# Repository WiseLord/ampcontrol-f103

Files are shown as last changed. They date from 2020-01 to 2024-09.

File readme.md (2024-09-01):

# Ampcontrol (STM32F103 / F303 version)

Ampcontrol is an control module for your DIY audio amplifier.
It supports various I²C-controlled audioprocessors and FM tuners.
Also, some other third-party devices are supported.

Some videos related to the device can be found at
[Youtube](https://www.youtube.com/playlist?list=PLfv57leyFFd1C61HgnKE3e_OFIXMBtf-D)

## Hardware support

- Graphic color TFT displays based on various controllers:
  - 160x128: ILI9163, S6D0144, ST7735;
  - 176x132: L2F50126, LPH9157, LS020, SSD1286A;
  - 220x176: HX8340, ILI9225, LGDP4524, S6D0164;
  - 320x240: HX8347A, HX8347D, ILI9320, ILI9341, MC2PA8201, S6D0129, S6D0139, SPFD5408, SSD1289, SSD2119;
  - 400x240: ILI9327, S6D04D1, ST7793;
  - 480x320: HX8357C, ILI9481, ILI9486, R61581, RM68140, ST7796S.

- Audio processors with I²C bus:
  - TDA7439, TDA731X, PT232X, TDA7418, TDA7719.

- FM tuners with I²C bus:
  - RDA580X, SI470X, TEA5767.

- Bluetooth modules
  - CSR8645, BK8000L (GPIO-based control via PCF8574x I²C expander);
  - BT201 (USART-based control).

- USB HID
  - Meida player on the PC can be controlled (Play/Pause and so on) by the device.

- KaRadio and MPD support
  - The device can act as "KaRadio plugin" via USART2 to add web radio support via ESP32. Alternatively, 
it can control MPD server running on Linux (for example, Raspberry PI).

More specific info can be found in [documentation](doc) pages.

## Building the code

[GNU Arm Embedded Toolchain](https://developer.arm.com/tools-and-software/open-source-software/developer-tools/gnu-toolchain/gnu-rm/downloads)
is required to build the project.

The project build system is based on [GNU Make](https://www.gnu.org/software/make/).
Linux users must have it already installed or they can easily do it.
For Windows users there is a port exists.
In both cases, both toolchain and make binaries should be added to the system PATH.

The process of building is very simple and doesn't depend on any other software installed.

### Default build (ILI9341 display with SPI wiring):

`make`

### Build for the specific STM32 MCUs, display and wiring:

`make STM32_MCU=F303CB DISPLAY=R61581 DISPVAR=8BIT`

The list of supported display controllers and MCUs can be found in Makefile or build_all.sh script.

## Schematics and wiring

The schematic and PCB files for the device itself in KiCad format can be found 
in [kicad/ampcontrol-f103](kicad/ampcontrol-f103) directory.

## Useful links

* [Firmware releases](https://github.com/WiseLord/ampcontrol-f103/releases)

* [The article (in Russian)](https://radiokot.ru/artfiles/6484/)

* [Forum thread (in Russian)](https://radiokot.ru/forum/viewtopic.php?f=2&t=158605)

* [Youtube playlist](https://www.youtube.com/playlist?list=PLfv57leyFFd1C61HgnKE3e_OFIXMBtf-D)

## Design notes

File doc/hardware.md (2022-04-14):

# TFT display

The project supports Graphic color TFT displays based on various controllers:

- 160x128: ILI9163, S6D0144, ST7735
- 176x132: L2F50126, LPH9157, LS020, SSD1286A
- 220x176: HX8340, ILI9225, LGDP4524, S6D0164
- 320x240: HX8347A, HX8347D, ILI9320, ILI9341, MC2PA8201, S6D0129, S6D0139, SPFD5408, SSD1289, SSD2119
- 400x240: ILI9327, S6D04D1, ST7793
- 480x320: HX8357C, ILI9481, ILI9486, R61581, RM68140, ST7796S

## 8-bit display connection:

D0-D7 (data bus): PB0-PB7
RD (read pin): pull to 3.3V
WR: (write pin): PB15
RS: (register select): PB14
CS: (chip select): PB12
RST: (reset): pull to 3.3V
BCKL: (backlight): PC13

## SPI display connection
CS: (chip select): PB12
RST: (reset): pull to 3.3V
DC: (data/command): PB14
SDI: (slave data input): PB15 (hardware SPI2 MOSI)
SCK: (slave clock): PB13 (hardware SPI2 SCK)
LED: (backlight): PC13
SDO: (slave data ooutput): pull to 3.3V

## Audiocontrollers and FM tuners

Most of the external chips are connected via I²C bus (hardware SPI1)

SDA: PB9
SCL: PB8

Si4703 tuner with 32768kHz quartz also needs reset pin connection:

RST: PA15

## MUTE and STBY control

When entering standby mode, it's useful to disable powering some parts of the whole projects
(like audio amplifier, audioprocessor, etc). So, only ampcontrol control module itself can
be left powered with lower display brighness. STBY pin can be used to control a relay or
another swtitch doing this.

Also, switching between inputs, powering on/off can produce audible clicks in acoustic system.
MUTE pin can be used to mute an amplifier at these moments.

STBY: PB10
MUTE: PB11

## Remote control

Standard TSOP IR receiver is used to get control commands from IR remote.

IR: PA8

## BT201 bluetooth module

USART1 used for communications with the module. So, playback is fully controlled as well as
an information about current song from USB or SDCARD is retreived

TX: PA9
RX: PA10

## Bluetooth modules like BK8000L or CSR8645

These modules don't have known interface to communicate with MCUs. But they have
GPIOs to connect buttons for such functions as PLAY/PAUSE and so on.

To control such kind of bluetooth modules, it's possible to use PCF8574 I²C bus expander
to emulate buttons presses to execute corresponding functions. It's connected to the project
via I²C line:

SDA: PB9
SCL: PB8

Then, the correct I²C address (depends on PCF8574 address input pins conditions)
should be selected in ampcontrol settings.

PCF5874 is connected to the BT module in this way (see i2cexp.h):

NEXT_TRACK: P5
PREV_TRACK: P4
NEXT_INPUT: P3
PLAY_PAUSE: P2

To emulate button press, PCF8574 sends short (200ms) positive impulse on the pin.

## KaRadio or MPD

The device can act as a "plugin" for KaRadio/KaRadio32 projects. The control and all
communications are done via USART2 connection

TX: PA2
RX: PA3

Also, instead of KaRadio it's possible to control MPD (Music Player Daemon). The board with
MPD (e.g. Raspberry Pi or alternative) need to be prepared and it should include mpd-uart.py 
script running. This script makes implements a communication between Ampcontrol's USART2 and
the board's MPD daemon. Python3 packages pyserial and python-mpd2 need to be installed.

## USB

When connectetd to the PC via hardware USB, the project acts as "USB keyboard" and sends
multimedia keys to the PC when a button on front panel or remote control is pressed. Thus,
playback in active multimedia player on PC supporting media keys can be controlled.

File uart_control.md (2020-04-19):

# UART control description

Commands to control the device via uart are shown below.

Lines starting with '##' are the output from the device,
an answer on user actions or control commands.

The commands set is under development and will be extended
in the future.

## 1. Power control

**amp.on**                      - Power on  
  ##AMP.STATUS#: ACTIVE  
  ##AMP.AUDIO.IC#: TDA7439  
  ##AMP.AUDIO.INPUT#: 0  
  ##AMP.AUDIO.VOLUME#: -50  
  ##AMP.AUDIO.BASS#: 3  
  ##AMP.AUDIO.MIDDLE#: 1  
  ##AMP.AUDIO.TREBLE#: 2  
  ##AMP.AUDIO.FRONTREAR#: 0  
  ##AMP.AUDIO.BALANCE#: 0  
  ##AMP.AUDIO.CENTER#: 0  
  ##AMP.AUDIO.SUBWOOFER#: 0  
  ##AMP.AUDIO.PREAMP#: 0  

**amp.off**                     - Power off  
  ##AMP.STATUS#: STANDBY  

**amp.switch**                  - Toggle the power  
  ##AMP.STATUS#: STANDBY  

**amp.status**                  - Show current power status  
  ##AMP.STATUS#: ACTIVE  

Commands above work always. Commands below work only in ACTIVE status

## 2. Audio control

**amp.audio**                   - Show selected audioproc name  
  ##AMP.AUDIO.IC#: TDA7439  

### Inputs

**amp.input**                   - Show current input  
 ##AMP.AUDIO.INPUT#: 2  

**amp.input 1**                 - Select input (starting from 0)  
  ##AMP.AUDIO.INPUT#: 1  
  ##AMP.AUDIO.GAIN#: 0  

**amp.input.next**              - Switch to next input  
  ##AMP.AUDIO.INPUT#: 3  
  ##AMP.AUDIO.GAIN#: 0  

**amp.input.prev**              - Switch to previous input  
  ##AMP.AUDIO.INPUT#: 2  
  ##AMP.AUDIO.GAIN#: 0  

### Volume, bass, middle. treble:

**amp.volume**                  - Show volume level  
  ##AMP.AUDIO.VOLUME#: -53  

**amp.bass.inc**                - Increase bass level  
  ##AMP.AUDIO.BASS#: 4  

**amp.middle.dec**              - Decrease middle level  
  ##AMP.AUDIO.MIDDLE#: 0  

**amp.treble 3**                - Decrease treble level  
  ##AMP.AUDIO.TREBLE#: 3  

## 3. Tuner control

**amp.tuner**                   - Show selected tuner name  
  ##AMP.TUNER.IC#: RDA5807  

**amp.tuner.freq**              - Show tuned frequency  
  ##AMP.TUNER.FREQ#: 9950  

**amp.tuner.freq 9980**         - Tune frequency  
  ##AMP.TUNER.FREQ#: 9980

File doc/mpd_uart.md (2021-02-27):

# MPD UART setup

Music Player Daemon is an application for playing music. It can be installed in any Linux, e.g:

`sudo apt install mpd`

MPD itself is a server part that only plays music. To control it, another application (client)
should be used.

Script mpd-uart.py acts like a client for MPD and is responsible for communications between
MPD daemon and Ampcontrol. It needs some python packages installed:

`sudo apt install pyserial`
`sudo apt install python-mpd2`

## Running on Linux PC

The easiest way is using USB-UART dongle. In Linux it is usually visible in system as /dev/ttyUSB0.
So, to run mpd-uart the following command should be executed:

`python3 /path/to/mpd-uart.py -p /dev/ttyUSB0`

Now, when USB-UART is connected to Ampcontrol's USART2, it's possible to control MPD instance on PC.
It works until the script is running.

## Running on Raspberry PI

Raspberry PI have GPIO header than includes UART pins. Firstly, it should be enabled on the board.
For example, in Raspi OS it can be done via "raspi-config" utility. Alternatively, it can be done
manually, by adding "enable_uart=1" parameter to /boot/config.txt file and removing any 'console=XXX`
parameters from /boot/cmdline.txt, except XXX=tty1.

After reboot the header UART (pins 8 and 10) are accessable, and mpd-uart (for instance, placed in
/home/pi/ folder) can be run as:

`python3 /home/pi/mpd-uart.py -p /dev/ttyS0`

Alternatively, the port can be specified in the script mpd-uart.py itself.

Probably, '/dev/serial0' should be used depending on RPi version.

## Daemon mode for mpd-uart.py

It's not convenient to run mpd-uart.py manually. So, it's good idea to run it as a system service.
For Raspi OS, that uses systemd, mpd-uart.service config was written.

To make it work, "mpd-uart.service" file should be placed to /etc/systemd/system/. After the new
service can be enabled for autoboot via the following command:

`sudo systemctl enable mpd-uart.service`

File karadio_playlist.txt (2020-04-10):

{"Name":"","URL":"","File":"","Port":"0","ovol":"0"}
{"Name":"Euroradio FM - SoftRock","URL":"stream1.euroradio.fm","File":"/euroradio3","Port":"8000","ovol":"0"}
{"Name":"Euroradio FM - Толькі BY","URL":"stream1.euroradio.fm","File":"/euroradio4","Port":"8000","ovol":"0"}
{"Name":"Euroradio FM - Alternative","URL":"stream1.euroradio.fm","File":"/euroradio1","Port":"8000","ovol":"0"}
{"Name":"Альфа Радио 107.9","URL":"listen.alpha.by","File":"/","Port":"8009","ovol":"0"}
{"Name":"Мелодии века 96.2","URL":"93.84.112.253","File":"/MV128","Port":"8010","ovol":"0"}
{"Name":"Радио UNISTAR 99.5 (Hot AC)","URL":"stream.hoster.by","File":"/unistar/unistar-256/icecast.audio","Port":"80","ovol":"0"}
{"Name":"Беларусь 102.0","URL":"video.tvr.by","File":"/belfm","Port":"8000","ovol":"0"}
{"Name":"Канал Культура 1125","URL":"video.tvr.by","File":"/culture","Port":"8000","ovol":"0"}
{"Name":"Радио Мир 107.1","URL":"217.23.126.106","File":"/radio2.mir","Port":"8002","ovol":"0"}
{"Name":"Радыё Рацыя 99.2","URL":"air.racyja.com","File":"/racja256","Port":"8000","ovol":"0"}
{"Name":"Юмор FM 93.7","URL":"live.humorfm.by","File":"/veseloe","Port":"8000","ovol":"0"}
{"Name":"Радыё Сталіца 105.1","URL":"video.tvr.by","File":"/stolica","Port":"8000","ovol":"0"}
{"Name":"","URL":"","File":"","Port":"0","ovol":"0"}
{"Name":"","URL":"","File":"","Port":"0","ovol":"0"}
{"Name":"","URL":"","File":"","Port":"0","ovol":"0"}
{"Name":"","URL":"","File":"","Port":"0","ovol":"0"}
{"Name":"","URL":"","File":"","Port":"0","ovol":"0"}
{"Name":"","URL":"","File":"","Port":"0","ovol":"0"}
{"Name":"","URL":"","File":"","Port":"0","ovol":"0"}
{"Name":"","URL":"","File":"","Port":"0","ovol":"0"}
{"Name":"","URL":"","File":"","Port":"0","ovol":"0"}
{"Name":"","URL":"","File":"","Port":"0","ovol":"0"}
{"Name":"","URL":"","File":"","Port":"0","ovol":"0"}
{"Name":"","URL":"","File":"","Port":"0","ovol":"0"}
{"Name":"","URL":"","File":"","Port":"0","ovol":"0"}
{"Name":"","URL":"","File":"","Port":"0","ovol":"0"}
{"Name":"","URL":"","File":"","Port":"0","ovol":"0"}
{"Name":"","URL":"","File":"","Port":"0","ovol":"0"}
{"Name":"","URL":"","File":"","Port":"0","ovol":"0"}
{"Name":"","URL":"","File":"","Port":"0","ovol":"0"}
{"Name":"","URL":"","File":"","Port":"0","ovol":"0"}
{"Name":"","URL":"","File":"","Port":"0","ovol":"0"}
{"Name":"","URL":"","File":"","Port":"0","ovol":"0"}
{"Name":"","URL":"","File":"","Port":"0","ovol":"0"}
{"Name":"","URL":"","File":"","Port":"0","ovol":"0"}
{"Name":"","URL":"","File":"","Port":"0","ovol":"0"}
{"Name":"","URL":"","File":"","Port":"0","ovol":"0"}
{"Name":"","URL":"","File":"","Port":"0","ovol":"0"}
{"Name":"","URL":"","File":"","Port":"0","ovol":"0"}
{"Name":"","URL":"","File":"","Port":"0","ovol":"0"}
{"Name":"","URL":"","File":"","Port":"0","ovol":"0"}
{"Name":"","URL":"","File":"","Port":"0","ovol":"0"}
{"Name":"","URL":"","File":"","Port":"0","ovol":"0"}
{"Name":"","URL":"","File":"","Port":"0","ovol":"0"}
{"Name":"","URL":"","File":"","Port":"0","ovol":"0"}
{"Name":"","URL":"","File":"","Port":"0","ovol":"0"}
{"Name":"","URL":"","File":"","Port":"0","ovol":"0"}
{"Name":"","URL":"","File":"","Port":"0","ovol":"0"}
{"Name":"","URL":"","File":"","Port":"0","ovol":"0"}
{"Name":"VOA Learning English (США)","URL":"voa-91.akacast.akamaistream.net","File":"/7/913/314276/v1/ibb.akacast.akamaistream.net/voa-91.m3u","Port":"80","ovol":"0"}
{"Name":"BBC World Service UK","URL":"bbcmedia.ic.llnwd.net","File":"/stream/bbcwssc_mp1_ws-eieuk","Port":"80","ovol":"0"}
{"Name":"BBC Radio 4 Extra (Юмор)","URL":"bbcmedia.ic.llnwd.net","File":"/stream/bbcmedia_radio4extra_mf_p","Port":"80","ovol":"0"}
{"Name":"","URL":"","File":"","Port":"0","ovol":"0"}
{"Name":"","URL":"","File":"","Port":"0","ovol":"0"}
{"Name":"","URL":"","File":"","Port":"0","ovol":"0"}
{"Name":"","URL":"","File":"","Port":"0","ovol":"0"}
{"Name":"","URL":"","File":"","Port":"0","ovol":"0"}
{"Name":"","URL":"","File":"","Port":"0","ovol":"0"}
{"Name":"","URL":"","File":"","Port":"0","ovol":"0"}
{"Name":"","URL":"","File":"","Port":"0","ovol":"0"}
{"Name":"","URL":"","File":"","Port":"0","ovol":"0"}
{"Name":"","URL":"","File":"","Port":"0","ovol":"0"}
{"Name":"","URL":"","File":"","Port":"0","ovol":"0"}
{"Name":"","URL":"","File":"","Port":"0","ovol":"0"}
{"Name":"","URL":"","File":"","Port":"0","ovol":"0"}
{"Name":"","URL":"","File":"","Port":"0","ovol":"0"}
{"Name":"","URL":"","File":"","Port":"0","ovol":"0"}
{"Name":"","URL":"","File":"","Port":"0","ovol":"0"}
{"Name":"","URL":"","File":"","Port":"0","ovol":"0"}
{"Name":"","URL":"","File":"","Port":"0","ovol":"0"}
{"Name":"","URL":"","File":"","Port":"0","ovol":"0"}
{"Name":"","URL":"","File":"","Port":"0","ovol":"0"}
{"Name":"","URL":"","File":"","Port":"0","ovol":"0"}
{"Name":"","URL":"","File":"","Port":"0","ovol":"0"}
{"Name":"","URL":"","File":"","Port":"0","ovol":"0"}
{"Name":"","URL":"","File":"","Port":"0","ovol":"0"}
{"Name":"","URL":"","File":"","Port":"0","ovol":"0"}
{"Name":"","URL":"","File":"","Port":"0","ovol":"0"}
{"Name":"","URL":"","File":"","Port":"0","ovol":"0"}
{"Name":"","URL":"","File":"","Port":"0","ovol":"0"}
{"Name":"","URL":"","File":"","Port":"0","ovol":"0"}
{"Name":"","URL":"","File":"","Port":"0","ovol":"0"}
{"Name":"","URL":"","File":"","Port":"0","ovol":"0"}
{"Name":"","URL":"","File":"","Port":"0","ovol":"0"}
{"Name":"","URL":"","File":"","Port":"0","ovol":"0"}
{"Name":"","URL":"","File":"","Port":"0","ovol":"0"}
{"Name":"","URL":"","File":"","Port":"0","ovol":"0"}
{"Name":"","URL":"","File":"","Port":"0","ovol":"0"}
{"Name":"","URL":"","File":"","Port":"0","ovol":"0"}
{"Name":"","URL":"","File":"","Port":"0","ovol":"0"}
{"Name":"","URL":"","File":"","Port":"0","ovol":"0"}
{"Name":"","URL":"","File":"","Port":"0","ovol":"0"}
{"Name":"","URL":"","File":"","Port":"0","ovol":"0"}
{"Name":"","URL":"","File":"","Port":"0","ovol":"0"}
{"Name":"","URL":"","File":"","Port":"0","ovol":"0"}
{"Name":"","URL":"","File":"","Port":"0","ovol":"0"}
{"Name":"","URL":"","File":"","Port":"0","ovol":"0"}
{"Name":"","URL":"","File":"","Port":"0","ovol":"0"}
{"Name":"","URL":"","File":"","Port":"0","ovol":"0"}
{"Name":"RTL","URL":"streaming.radio.rtl.fr","File":"/rtl-1-48-192","Port":"80","ovol":"-4"}
{"Name":"RJM French","URL":"listen.radionomy.com","File":"/rjm-french.m3u","Port":"80","ovol":"0"}
{"Name":"France1Max","URL":"listen.radionomy.com","File":"/france1max.m3u","Port":"80","ovol":"0"}
{"Name":"Golden50/70sHits","URL":"listen.radionomy.com","File":"/golden-50-70s-hits","Port":"80","ovol":"0"}
{"Name":"Nostalgie Chansons Francaises","URL":"cdn.nrjaudio.fm","File":"/adwz1/fr/30611/aac_64.mp3","Port":"80","ovol":"0"}
{"Name":"Romantic Dreams","URL":"listen.radionomy.com","File":"/romanticdreams","Port":"80","ovol":"0"}
{"Name":"MusicOnly FM","URL":"listen.radionomy.com","File":"/musiconly-fm","Port":"80","ovol":"0"}
{"Name":"Nice oldies","URL":"listen.radionomy.com","File":"/niceoldies","Port":"80","ovol":"0"}
{"Name":"Radio 45 tours","URL":"listen.radionomy.com","File":"/45tours","Port":"80","ovol":"0"}
{"Name":"RFI Monde","URL":"live02.rfi.fr","File":"/rfimonde-64.mp3","Port":"80","ovol":"0"}
{"Name":"Alpes 1 Gap","URL":"alpes1gap.ice.infomaniak.ch","File":"/alpes1gap-high.mp3","Port":"80","ovol":"0"}
{"Name":"Alpes 1 Années 80","URL":"allzic08.ice.infomaniak.ch","File":"/allzic08.mp3","Port":"80","ovol":"0"}
{"Name":"Alpes 1 Années 90","URL":"allzic24.ice.infomaniak.ch","File":"/allzic24.mp3","Port":"80","ovol":"0"}
{"Name":"Autoroute info sud","URL":"media.autorouteinfo.fr","File":"/direct_sud.mp3.m3u","Port":"8000","ovol":"0"}
{"Name":"Autoroute Info Nord","URL":"media.autorouteinfo.fr","File":"/direct_nord.mp3.m3u","Port":"8000","ovol":"0"}
{"Name":"California 101","URL":"www.california101radio.com","File":"/california101.pls","Port":"80","ovol":"0"}
{"Name":"Chante France","URL":"stream1.chantefrance.com","File":"/Chante_France.m3u","Port":"80","ovol":"0"}
{"Name":"Radio Grenouille","URL":"live.radiogrenouille.com","File":"/live.m3u","Port":"80","ovol":"0"}
{"Name":"Alter Nantes","URL":"diffusion.lafrap.fr","File":"/alternantes.mp3.m3u","Port":"80","ovol":"0"}
{"Name":"Impact FM","URL":"broadcast.infomaniak.ch","File":"/impactfm-128.mp3.m3u","Port":"80","ovol":"0"}
{"Name":"MFM","URL":"mfm.ice.infomaniak.ch","File":"/mfm-128.mp3","Port":"80","ovol":"0"}
{"Name":"OUI FM","URL":"broadcast.infomaniak.ch","File":"/ouifm-high.mp3.m3u","Port":"80","ovol":"0"}
{"Name":"OUI FM Alternatif","URL":"broadcast.infomaniak.net","File":"/ouifm2.mp3.m3u","Port":"80","ovol":"0"}
{"Name":"OUI FM Collector","URL":"ouifm3.ice.infomaniak.ch","File":"/ouifm3.mp3.m3u","Port":"80","ovol":"0"}
{"Name":"Hot Mix","URL":"www.hotmixradio.fr","File":"/hotmixhit.m3u","Port":"80","ovol":"0"}
{"Name":"Classical WETA 90.9 FM - Washington D.C.","URL":"38.100.128.106","File":"/listen.pls?sid=1","Port":"8000","ovol":"0"}
{"Name":"Radio Bloodstream","URL":"uk1.internet-radio.com","File":"/live.m3u","Port":"8294","ovol":"0"}
{"Name":"Classic Rock Florida","URL":"us2.internet-radio.com","File":"/listen.pls","Port":"8046","ovol":"0"}
{"Name":"Lala Radio","URL":"broadcast.infomaniak.ch","File":"/lalaradio-high.mp3.m3u","Port":"80","ovol":"0"}
{"Name":"SUN - LE SON UNIQUE A NANTES ","URL":"80.82.229.202","File":"/sunhd.mp3","Port":"8000","ovol":"0"}
{"Name":"Los 40 Principales","URL":"provisioning.streamtheworld.com","File":"/pls/LOS40.pls","Port":"80","ovol":"0"}
{"Name":"Earth Uk","URL":"media-ice.musicradio.com","File":"/HeartLondonMP3.m3u","Port":"80","ovol":"0"}
{"Name":"Public Domain Classical - Swiss Internet Radio","URL":"www.swissradio.ch","File":"/streams/6034.asx","Port":"80","ovol":"0"}
{"Name":"Minster Radio Uk","URL":"str1.sad.ukrd.com","File":"/minster.m3u","Port":"80","ovol":"0"}
{"Name":"Zenith Classic Rock Dublin","URL":"148.163.81.10","File":"/listen.pls?sid=1","Port":"8006","ovol":"0"}
{"Name":"Vibration FM Suise","URL":"vibration.stream2net.eu","File":"/listen.pls","Port":"8130","ovol":"0"}
{"Name":"Vibration PopRock Suisse","URL":"vibrationpoprock.stream2net.eu","File":"/listen.pls","Port":"8260","ovol":"0"}
{"Name":"Vibration Latina Suisse","URL":"vibracionlatina.stream2net.eu","File":"/listen.pls","Port":"8410","ovol":"0"}
{"Name":"Vibration classic hit Suisse","URL":"vibrationclassic80.stream2net.eu","File":"/listen.pls","Port":"8060","ovol":"0"}
{"Name":"Traxx Suisse","URL":"traxx001.ice.infomaniak.ch","File":"/traxx009-low.mp3.m3u","Port":"80","ovol":"0"}
{"Name":"Rhone FM","URL":"broadcast.infomaniak.ch","File":"/rhonefm-high.mp3.m3u","Port":"80","ovol":"0"}
{"Name":"Motown Magic Oldies","URL":"airspectrum.cdnstream1.com","File":"/1302_192.m3u","Port":"8024","ovol":"0"}
{"Name":"California-101 The Westcoast Radio","URL":"www.california101radio.com","File":"/california101.pls","Port":"80","ovol":"0"}
{"Name":"All Request Show","URL":"www.streamvortex.com","File":"/listen.pls?sid=1","Port":"10230","ovol":"0"}
{"Name":"SALSA BRAVA RADIO","URL":"206.190.130.180","File":"/","Port":"8053","ovol":"0"}
{"Name":"1.FM - ABSOLUTE TOP 40 RADIO","URL":"69.46.90.245","File":"/","Port":"8078","ovol":"0"}
{"Name":"Magic Oldies Florida","URL":"listen.shoutcast.com","File":"/MagicOldiesFlorida","Port":"80","ovol":"0"}
{"Name":"Coast FM TENERIFE","URL":"uk1.internet-radio.com","File":"/","Port":"15614","ovol":"0"}
{"Name":"French Radio London","URL":"radio.canstream.co.uk","File":"/live.mp3.m3u","Port":"8100","ovol":"0"}
{"Name":"VOXINOX la webradio des Jeunes Seniors","URL":"94.23.41.123","File":"/","Port":"8010","ovol":"0"}
{"Name":"Voxinox 2","URL":"94.23.41.123","File":"/;?.mp3","Port":"8020","ovol":"0"}
{"Name":"Sud Radio","URL":"start-sud.ice.infomaniak.ch","File":"/start-sud-high.mp3","Port":"80","ovol":"0"}
{"Name":"100% Hit","URL":"100radio-hit.ice.infomaniak.ch","File":"/100radio-hit-128.mp3","Port":"80","ovol":"0"}
{"Name":"100% 80","URL":"100radio-80.ice.infomaniak.ch","File":"/100radio-80-128.mp3","Port":"80","ovol":"0"}
{"Name":"100% 90","URL":"100radio-90.ice.infomaniak.ch","File":"/100radio-90-64.aac","Port":"80","ovol":"0"}
{"Name":"100% Carcassonne","URL":"100radio-carcassonne.ice.infomaniak.ch","File":"/100radio-carcassonne-128.mp3","Port":"80","ovol":"0"}
{"Name":"Ringfm","URL":"shout.babahh.com","File":"/ringfm","Port":"80","ovol":"0"}
{"Name":"Europa FM Spain","URL":"212.129.60.86","File":"/listen.pls","Port":"9968","ovol":"0"}
{"Name":"Cadena Spain","URL":"provisioning.streamtheworld.com","File":"/pls/CADENADIAL.pls","Port":"80","ovol":"0"}
{"Name":"Europa FM Spain","URL":"212.129.60.86","File":"/listen.pls","Port":"9968","ovol":"0"}
{"Name":"Classic Hits 4FM Ireland","URL":"sirius.shoutca.st","File":"/listen.pls?sid=1","Port":"8166","ovol":"0"}
{"Name":"Sunshine Ireland","URL":"sirius.shoutca.st","File":"/listen.pls?sid=1","Port":"8291","ovol":"0"}
{"Name":"Antenna 1 Italy","URL":"s3.mediastreaming.it","File":"/listen.pls","Port":"7568","ovol":"0"}
{"Name":"Antenna 2 Italy","URL":"wma03.fluidstream.net","File":"/listen.pls","Port":"9070","ovol":"0"}
{"Name":"FM Italia Italy","URL":"onair7.xdevel.com","File":"/listen.pls","Port":"8700","ovol":"0"}
{"Name":"Onda Libera Italy","URL":"s6.mediastreaming.it","File":"/listen.pls","Port":"9064","ovol":"0"}
{"Name":"Hi On Line Pop netherland","URL":"mediaserv30.live-streams.nl","File":"/","Port":"8086","ovol":"0"}
{"Name":"Hi On Line World","URL":"mediaserv38.live-streams.nl","File":"/","Port":"8027","ovol":"0"}
{"Name":"Hi On Line Latin","URL":"mediaserv33.live-streams.nl","File":"/","Port":"8034","ovol":"0"}
{"Name":"Hi On Line Gold","URL":"mediaserv30.live-streams.nl","File":"/","Port":"8000","ovol":"0"}
{"Name":"trancebase","URL":"listen.trancebase.fm","File":"/tunein-aacplus-pls?sid=1","Port":"80","ovol":"0"}
{"Name":"PARTY VIBE RADIO ","URL":"www.partyviberadio.com","File":"/listen.pls?sid=1","Port":"8000","ovol":"0"}
{"Name":"Party Vibe Top 40","URL":"www.partyviberadio.com","File":"/listen.pls?sid=1","Port":"8024","ovol":"0"}
{"Name":"The Cardigans","URL":"stream.pcradio.biz","File":"/The_Cardigans-hi","Port":"8000","ovol":"0"}
{"Name":"The Beach Boys","URL":"stream.pcradio.biz","File":"/The_Beach_Boys-hi","Port":"8000","ovol":"0"}
{"Name":"Top 200","URL":"stream.pcradio.biz","File":"/Top_200-hi","Port":"8000","ovol":"0"}
{"Name":"The Corrs","URL":"stream.pcradio.biz","File":"/The_Corrs-hi","Port":"8000","ovol":"0"}
{"Name":"Pink Floyd","URL":"stream.pcradio.biz","File":"/Pink_Floyd-hi","Port":"8000","ovol":"0"}
{"Name":"BoneyM","URL":"stream.pcradio.biz","File":"/BoneyM-hi","Port":"8000","ovol":"0"}
{"Name":"Nirvana","URL":"stream.pcradio.biz","File":"/Nirvana-hi","Port":"8000","ovol":"0"}
{"Name":"The Prodigy","URL":"stream.pcradio.biz","File":"/The_Prodigy-hi","Port":"8000","ovol":"0"}
{"Name":"Radio Ici et Maintenant","URL":"radio.rim952.fr","File":"/stream.ogg.m3u","Port":"8001","ovol":"0"}
{"Name":"Radio libertaire","URL":"ecoutez.radio-libertaire.org","File":"/radiolib.m3u","Port":"8080","ovol":"0"}
{"Name":"Russe","URL":"stream.pcradio.biz","File":"/Ruki_Vverh-hi","Port":"8000","ovol":"0"}
{"Name":"Radio 101 Zagreb","URL":"live.radio101.hr","File":"/listen.pls","Port":"7066","ovol":"0"}
{"Name":"DI Radio Digital impulse","URL":"5.39.71.159","File":"/listen.pls?sid=1","Port":"8110","ovol":"0"}
{"Name":"test2","URL":"provisioning.streamtheworld.com","File":"/pls/program1aac.pls","Port":"80","ovol":"0"}
{"Name":"deltaradio_indie","URL":"stream.pcradio.biz","File":"/deltaradio_indie-low","Port":"8000","ovol":"0"}
{"Name":"Top club radionomy","URL":"listen.radionomy.com","File":"/topclub.m3u","Port":"80","ovol":"0"}
{"Name":"RadioMyMe radionomy","URL":"listen.radionomy.com","File":"/radiomyme-tv.m3u","Port":"80","ovol":"0"}
{"Name":"100% Hit Radionomy","URL":"listen.radionomy.com","File":"/100-hit-radio.m3u","Port":"80","ovol":"0"}
{"Name":"All 60S Radionomy","URL":"listen.radionomy.com","File":"/all60sallthetime-keepfreemusiccom.m3u","Port":"80","ovol":"0"}
{"Name":"Nostalgia Radionomy","URL":"listen.radionomy.com","File":"/radio-nostalgia.m3u","Port":"80","ovol":"0"}
{"Name":"MadeIn80 Radionomy","URL":"listen.radionomy.com","File":"/madein80.m3u","Port":"80","ovol":"0"}
{"Name":"Wood radio","URL":"streaming.radionomy.com","File":"/WoodRadio","Port":"80","ovol":"0"}
{"Name":"Hotmix 80","URL":"streamingads.hotmixradio.fm","File":"/hotmixradio-80-128.mp3","Port":"80","ovol":"0"}
{"Name":"Hotmix Frenchy","URL":"streamingads.hotmixradio.fm","File":"/hotmixradio-frenchy-128.mp3","Port":"80","ovol":"0"}
{"Name":"Hotmix Hits","URL":"streamingads.hotmixradio.fm","File":"/hotmixradio-hits-128.mp3","Port":"80","ovol":"0"}
{"Name":"Hotmix Funky","URL":"hotmixradio-frenchy.ice.infomaniak.ch","File":"/hotmixradio-funky-128.mp3","Port":"80","ovol":"0"}
{"Name":"Hotmix Lounge","URL":"hotmixradio-frenchy.ice.infomaniak.ch","File":"/hotmixradio-lounge-128.mp3","Port":"80","ovol":"0"}
{"Name":"Hotmix 90","URL":"streamingads.hotmixradio.fm","File":"/hotmixradio-90-128.mp3","Port":"80","ovol":"0"}
{"Name":"Hotmix Rock","URL":"streamingads.hotmixradio.fm","File":"/hotmixradio-rock-128.mp3","Port":"80","ovol":"0"}
{"Name":"Hotmix Hiphop","URL":"hotmixradio-frenchy.ice.infomaniak.ch","File":"/hotmixradio-hiphop-128.mp3","Port":"80","ovol":"0"}
{"Name":"Kiss FM","URL":"kissfm.ice.infomaniak.ch","File":"/kissfm-128.mp3","Port":"80","ovol":"0"}
{"Name":"Activ Radio","URL":"www.activradio.com","File":"/component/popupStream/ecouteSaintTienne.m3u","Port":"80","ovol":"0"}
{"Name":"","URL":"","File":"","Port":"0","ovol":"0"}
{"Name":"","URL":"","File":"","Port":"0","ovol":"0"}
{"Name":"","URL":"","File":"","Port":"0","ovol":"0"}
{"Name":"","URL":"","File":"","Port":"0","ovol":"0"}
{"Name":"","URL":"","File":"","Port":"0","ovol":"0"}
{"Name":"","URL":"","File":"","Port":"0","ovol":"0"}
{"Name":"","URL":"","File":"","Port":"0","ovol":"0"}
{"Name":"","URL":"","File":"","Port":"0","ovol":"0"}
{"Name":"","URL":"","File":"","Port":"0","ovol":"0"}
{"Name":"","URL":"","File":"","Port":"0","ovol":"0"}
{"Name":"","URL":"","File":"","Port":"0","ovol":"0"}
{"Name":"","URL":"","File":"","Port":"0","ovol":"0"}
{"Name":"","URL":"","File":"","Port":"0","ovol":"0"}
{"Name":"","URL":"","File":"","Port":"0","ovol":"0"}
{"Name":"","URL":"","File":"","Port":"0","ovol":"0"}
{"Name":"","URL":"","File":"","Port":"0","ovol":"0"}
{"Name":"","URL":"","File":"","Port":"0","ovol":"0"}
{"Name":"","URL":"","File":"","Port":"0","ovol":"0"}
{"Name":"","URL":"","File":"","Port":"0","ovol":"0"}
{"Name":"","URL":"","File":"","Port":"0","ovol":"0"}
{"Name":"","URL":"","File":"","Port":"0","ovol":"0"}
{"Name":"","URL":"","File":"","Port":"0","ovol":"0"}
{"Name":"","URL":"","File":"","Port":"0","ovol":"0"}
{"Name":"","URL":"","File":"","Port":"0","ovol":"0"}
{"Name":"","URL":"","File":"","Port":"0","ovol":"0"}
{"Name":"","URL":"","File":"","Port":"0","ovol":"0"}
{"Name":"","URL":"","File":"","Port":"0","ovol":"0"}
{"Name":"","URL":"","File":"","Port":"0","ovol":"0"}
{"Name":"","URL":"","File":"","Port":"0","ovol":"0"}
{"Name":"","URL":"","File":"","Port":"0","ovol":"0"}
{"Name":"","URL":"","File":"","Port":"0","ovol":"0"}
{"Name":"","URL":"","File":"","Port":"0","ovol":"0"}
{"Name":"","URL":"","File":"","Port":"0","ovol":"0"}
{"Name":"","URL":"","File":"","Port":"0","ovol":"0"}
{"Name":"","URL":"","File":"","Port":"0","ovol":"0"}
{"Name":"","URL":"","File":"","Port":"0","ovol":"0"}
{"Name":"","URL":"","File":"","Port":"0","ovol":"0"}
{"Name":"","URL":"","File":"","Port":"0","ovol":"0"}
{"Name":"","URL":"","File":"","Port":"0","ovol":"0"}
{"Name":"","URL":"","File":"","Port":"0","ovol":"0"}
{"Name":"","URL":"","File":"","Port":"0","ovol":"0"}
{"Name":"","URL":"","File":"","Port":"0","ovol":"0"}
{"Name":"","URL":"","File":"","Port":"0","ovol":"0"}
{"Name":"","URL":"","File":"","Port":"0","ovol":"0"}
{"Name":"","URL":"","File":"","Port":"0","ovol":"0"}
{"Name":"","URL":"","File":"","Port":"0","ovol":"0"}
{"Name":"","URL":"","File":"","Port":"0","ovol":"0"}
{"Name":"","URL":"","File":"","Port":"0","ovol":"0"}
{"Name":"","URL":"","File":"","Port":"0","ovol":"0"}
{"Name":"","URL":"","File":"","Port":"0","ovol":"0"}

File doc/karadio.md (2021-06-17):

# KaRadio and KaRadio32

Both project are web-radio implementation. First one is based on ESP8266
while the second is based on ESP-32.

Both projects have the same UART-based interface, so that Ampcontrol can
communicate with webradio

## Ka-Radio

Clone https://github.com/karawin/Ka-Radio

There is `ESP8266-Firmware` directory in the project with some useful
instructions how to build and flash the project. In `bin` subfolders
there are precompiled binaries.

Erasing ESP32:
```
esptool.py --baud 115200 --port /dev/ttyUSB0 erase_flash
```

Flash Ka-Radio:
```
esptool.py --baud 115200 --port /dev/ttyUSB0 write_flash \
    0x0000000 "./bin/boot_v1.6.bin" \
    0x0001000 "./bin/upgrade/user1.4096.new.4.bin" \
    0x0081000 "./bin/upgrade/user2.4096.new.4.bin" \
    0x03fc000 "./bin/esp_init_data_default.bin" \
    0x03fe000 "./bin/blank.bin" \
    -fs 4MB
```

## Ka-Radio32

Clone https://github.com/karawin/Ka-Radio32

There is `binaries` directory from where the firmware can be flashed
```
esptool.py --chip esp32 --port /dev/ttyUSB0 --baud 460800 \
    --before default_reset --after hard_reset write_flash -u \
    --flash_mode dio --flash_freq 40m --flash_size detect \
    0x1000  bootloader.bin \
    0x10000 KaRadio32.bin \
    0x8000  partitions.bin
```

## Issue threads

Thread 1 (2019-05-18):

8 bit mode SSD1289

ematt, 2019-05-18:
Hello,

I have always dreamed to have my own audio system, I got a real interest in this project.

I am trying to get this software working with a TFT_320QVT([pictures](https://www.amazon.ca/XCSOURCE-240x320-Screen-Driver-SSD1289/dp/B00XXEJLZU)) display in 8 bit mode without any success. Unfortunately I got little to no experience with graphical LCD's. I am stuck with a blank screen.

The progress so far:

**About the display**:
The seller states that the lcd controller is SSD1289
I have moved the R4 resistor to R5 to enable 8 bit interface as  matherp states here https://www.thebackshed.com/forum/forum_posts.asp?TID=7903 and soldered the J1 jumper because VCC is already 3.3V

**About the STM32 board**
Is a Blue Pill(STM32F103C8T6) dev board: https://wiki.stm32duino.com/index.php?title=Blue_Pill
I am using an ST-LINK v2 emulator to program it
gdb shows that the software runs normally on the STM32

**Wiring**:

Blue pill | LCD
-------- | --------
A0..A7 | DB0..DB7
B12 | CS
B14 | RS
B15 | WR
G | GND
3.3 | VCC

LED's LED_A is connected to a 3.3V in from the ST-LINK

**Project setup**:
```
diff --git a/Makefile b/Makefile
index 2abc0e2..c4098ab 100644
--- a/Makefile
+++ b/Makefile
@@ -1,7 +1,7 @@
 PROJECT = ampcontrol_f103

-DISPLAY = ILI9341
-DISPVAR = SPI
+DISPLAY = SSD1289
+DISPVAR = 8BIT

 APROC_LIST = TDA7439 TDA731X PT232X TDA7418
 TUNER_LIST = RDA580X SI470X TEA5767
@@ -195,7 +195,7 @@ CFLAGS += -MMD -MP -MT $(BUILD_DIR)/$(*F).o -MF $(BUILD_DIR)/$(*D)/$(*F).d
 LDSCRIPT = system/stm32f103c8tx_flash.ld
 LIBS = -lc -lm -lnosys
 LIBDIR =
-LDFLAGS = $(MCU) -specs=nosys.specs -specs=nano.specs -T$(LDSCRIPT) $(LIBDIR) $(LIBS) -Wl,-Map=$(BUILD_DIR)/$(TARGET).map,--cref -Wl,--gc-sections
+LDFLAGS = $(MCU) -specs=nosys.specs -specs=nano.specs -T$(LDSCRIPT) $(LIBDIR) $(LIBS) -Wl,-Map=$(BUILD_DIR)/$(TARGET).map,--cref -Wl,--gc-sections -L/usr/lib/arm-none-eabi/newlib/thumb
 #LDFLAGS = $(WARN) -mmcu=$(MCU) -Wl,--gc-sections -Wl,--relax

 # Main definitions
diff --git a/ampcontrol-f103.config b/ampcontrol-f103.config
index 77b055d..5716896 100644
--- a/ampcontrol-f103.config
+++ b/ampcontrol-f103.config
@@ -10,12 +10,13 @@
 //#define _LPH9157
 //#define _LS020
 //#define _SSD1286A
+#define _SSD1289

 //#define _HX8340
 //#define _ILI9225

 //#define _ILI9320
-#define _ILI9341
+//#define _ILI9341
 //#define _MC2PA8201
 //#define _S6D0129
 //#define _S6D0139
@@ -28,9 +29,9 @@
 //#define _ILI9486
 //#define _R61581

-//#define _DISP_8BIT
+#define _DISP_8BIT
 //#define _DISP_16BIT
-#define _DISP_SPI
+//#define _DISP_SPI
 //#define _DISP_HI_BYTE
 #define _DISP_LO_BYTE
 #define _DISP_320x240
diff --git a/pins.h b/pins.h
index 5cd9fe1..02ddf32 100644
--- a/pins.h
+++ b/pins.h
@@ -69,9 +69,9 @@ void pinsSetStby(bool value);
 #define RC_AR_ExtiLine          LL_GPIO_AF_EXTI_LINE8

 // TFT LCD pins
-#define DISP_DATA_LO_Port       GPIOB
-#define DISP_DATA_LO_Pin        (LL_GPIO_PIN_0 | LL_GPIO_PIN_1 | LL_GPIO_PIN_2 | LL_GPIO_PIN_3 | \
-                                 LL_GPIO_PIN_4 | LL_GPIO_PIN_5 | LL_GPIO_PIN_6 | LL_GPIO_PIN_7)
+#define DISP_DATA_LO_Port       GPIOA
+#define DISP_DATA_LO_Pin        (LL_GPIO_PIN_0 | LL_GPIO_PIN_1 | LL_GPIO_PIN_3 | LL_GPIO_PIN_4 | \
+                                 LL_GPIO_PIN_5 | LL_GPIO_PIN_6 | LL_GPIO_PIN_7 | LL_GPIO_PIN_2)

 // TFT parallel (8-bit) wiring
 #define DISP_CS_Port            GPIOB

```

WiseLord, 2019-05-18:
Did you try other drivers? I have an 8bit display with absolutely the same
pinout, but with ILI9431 controller. Also, originally it was 16bit and I
had to resolder a resistor on its flex board to switch it to 8bit.

сб, 18 мая 2019 г., 12:01 ematt <notifications@github.com>:

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

WiseLord, 2019-05-18:
also, do you have RD pulled up?

сб, 18 мая 2019 г., 12:33 WiseLord <wiselord1983@gmail.com>:

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

ematt, 2019-05-18:
RD is now pulled up and I've added a 100uF capacitor between VCC and GND on the LCD board.
Tried all other drivers with the same result, the screen remains blank.

Could you tell if wiring is right?

WiseLord, 2019-05-18:
Wiring looks OK. I guess the problem is that display might not properly
switched to 8bit mode.
I had a similar problem with similar LCD and first just put my display
aside. But later the guy who added the support of most display controllers
in this project gave me some hints about switching to 8bit.

сб, 18 мая 2019 г., 14:00 ematt <notifications@github.com>:

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

ematt, 2019-05-19:
I got it working with the following wiring:

Blue pill | LCD
-- | --
A0..A7 | DB0..DB7
B12 | CS
B14 | RS
B15 | WR
G | GND
3.3 | VCC

LCD pin | -
-- | --
RD | VCC
RESET | VCC
LED_A | VCC

Thank you so much for your help!

Closed 2019-05-19.

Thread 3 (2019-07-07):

Automatic input selection

ematt, 2019-07-07:
Hi WiseLord,

It would be extremely useful to have the possibility to switch the input without even touching the device.
In this way you could just turn on the TV or connect your phone to the Bluetooth input and the ampcontrol is already switching the input from whatever it was playing or it could even wake up from stand-by.
This could be done by using an analog multiplexer to route the audio inputs to MCP602's inputs.

What do you think?

WiseLord, 2019-07-07:
How ampcontrol can know if something is playing at some input, while it is
working with another one?

вс, 7 июл. 2019 г., 22:45 ematt <notifications@github.com>:

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

ematt, 2019-07-07:
A basic block scheme looks something like:
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
`Analog mux` block routes the audio inputs to PA0 and PA1 so it can scan the inputs.
The audio output is not affected because the sound processor is not involved at all, it just does his thing as usual.
`MCP602 ` block represents the OP amp block that is already on the board
I am not sure how the FFT algorithm will get affected by this. If it gets messed up we may need to use an additional pair of ADCs for this.

WiseLord, 2019-10-02:
Such block scheme increases the complexity of the device, demanding several audio procesors (I consider this Analogue mux as additional one). It simply won't work if there are simultaneous signals on several inputs, in addition making mess in ADC/FFT.
Also, when the system is in standby mode, everything is supposed to be powered off and signal routes are broken.

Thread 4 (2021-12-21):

ILI9488 Support?

metziv, 2021-12-21:
Hi!

Very nice projekt, I use for my own purposes.

I would switch to a bigger 3,5" display (ILI9488 SPI - 480X320), I tried write code to ILI9488 display.

With little success.:

https://kepkuldes.com/image/JfqxId

Will there be an update with an ILI9488 driver support in the near future?

Regard:
Geri12

metziv, 2021-12-25:
Nothing answer? I thought this project was more up to date. :( I hope one day I get some answer and that’s just a temporary state.

Closed 2022-01-01.

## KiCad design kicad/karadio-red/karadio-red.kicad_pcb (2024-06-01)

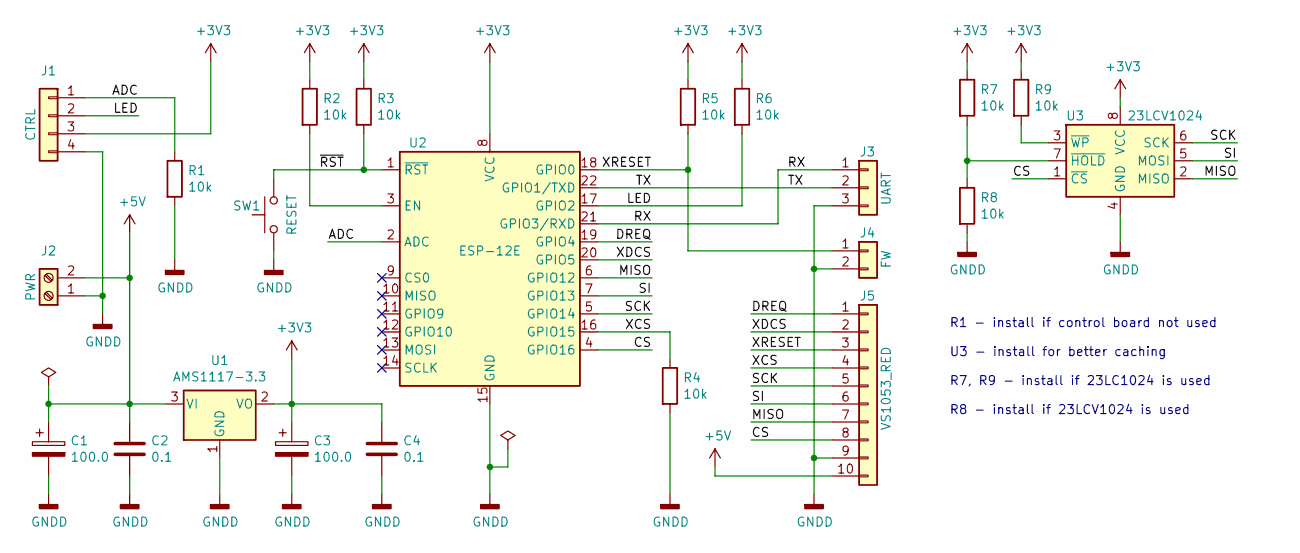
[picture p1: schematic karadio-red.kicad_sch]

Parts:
C1, C3: 100.0; CP_Radial_D6.3mm_P2.50mm
C2, C4: 0.1; C_1206_3216Metric
J1: CTRL; PinHeader_1x04_P2.54mm_Vertical
J2: PWR; TerminalBlock_bornier-2_P5.08mm
J3: UART; PinHeader_1x03_P2.54mm_Vertical
J4: FW; PinHeader_1x02_P2.54mm_Vertical
J5: VS1053_RED; PinSocket_1x10_P2.54mm_Vertical
R1, R2, R3, R4, R5, R6, R7, R8, R9: 10k; R_1206_3216Metric
SW1: RESET; SW_PUSH_6mm
U1: AMS1117-3.3; SOT-223-3_TabPin2
U2: ESP-12E
U3: 23LCV1024; SO-8_3.9x4.9mm_P1.27mm

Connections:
+3V3: C3.1, C4.1, J1.3, R2.1, R3.1, R5.1, R6.1, R7.1, R9.1, U1.2 (VO), U2.8 (VCC), U3.8 (VCC)
+5V: C1.1, C2.1, J2.2, J5.10, U1.3 (VI)
/ADC: J1.1, R1.1, U2.2 (ADC)
/CS: J5.8, U2.4 (GPIO16), U3.1 (~CS)
/DREQ: J5.1, U2.19 (GPIO4)
/LED: J1.2, R6.2, U2.17 (GPIO2)
/MISO: J5.7, U2.6 (GPIO12), U3.2 (MISO)
/RX: J3.1, U2.21 (GPIO3/RXD)
/SCK: J5.5, U2.5 (GPIO14), U3.6 (SCK)
/SI: J5.6, U2.7 (GPIO13), U3.5 (MOSI)
/TX: J3.2, U2.22 (GPIO1/TXD)
/XCS: J5.4, R4.1, U2.16 (GPIO15)
/XDCS: J5.2, U2.20 (GPIO5)
/XRESET: J4.1, J5.3, R5.2, U2.18 (GPIO0)
/~RST: R3.2, SW1.2, U2.1 (~RST)
GNDD: C1.2, C2.2, C3.2, C4.2, J1.4, J2.1, J3.3, J4.2, J5.9, R1.2, R4.2, R8.2, SW1.1, U1.1 (GND), U2.15 (GND), U3.4 (GND)
unnamed: R2.2, U2.3 (EN)
unnamed: R7.2, R8.1, U3.7 (~HOLD)
unnamed: R9.2, U3.3 (~WP)

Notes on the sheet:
R1 - install if control board not used U3 - install for better caching R7, R9 - install if 23LC1024 is used R8 - install if 23LCV1024 is used

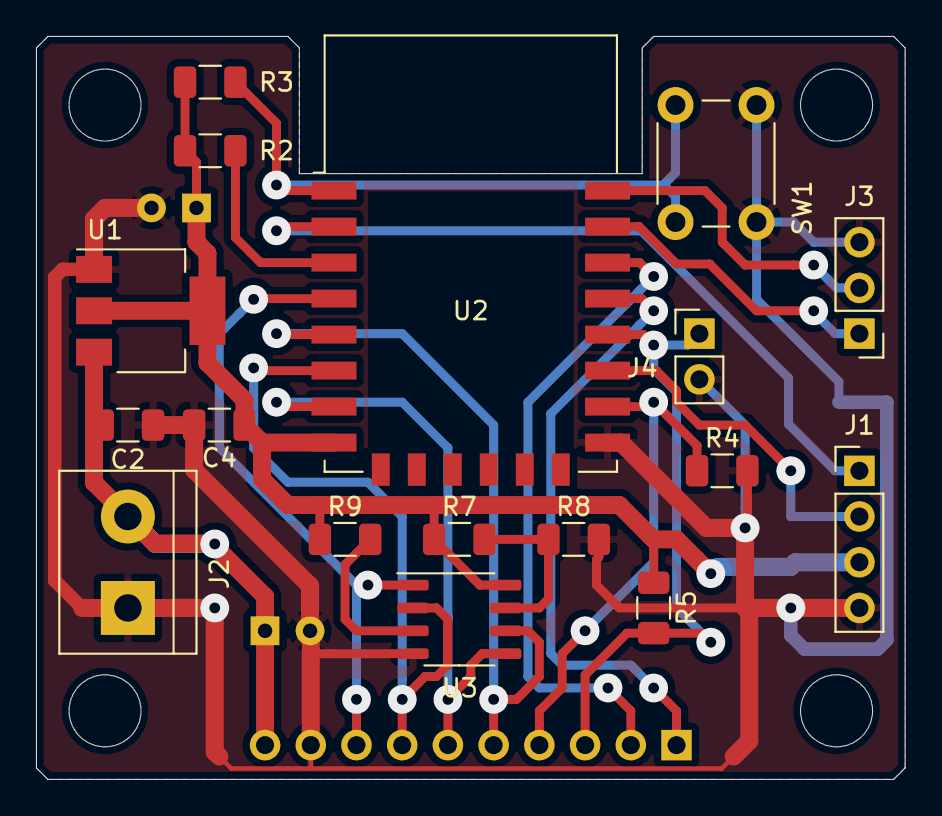
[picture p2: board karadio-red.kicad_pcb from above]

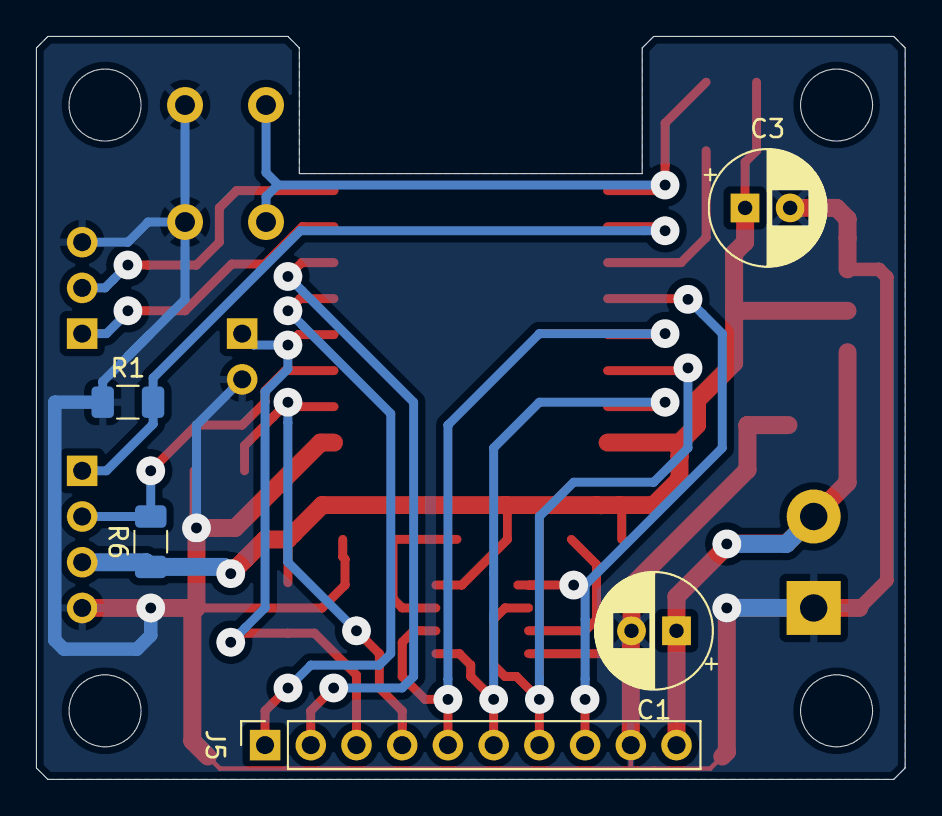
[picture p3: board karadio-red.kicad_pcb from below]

Board: 2 copper layers, 48.3 x 41.3 mm, 22 parts (5 on the bottom side), 19 nets.

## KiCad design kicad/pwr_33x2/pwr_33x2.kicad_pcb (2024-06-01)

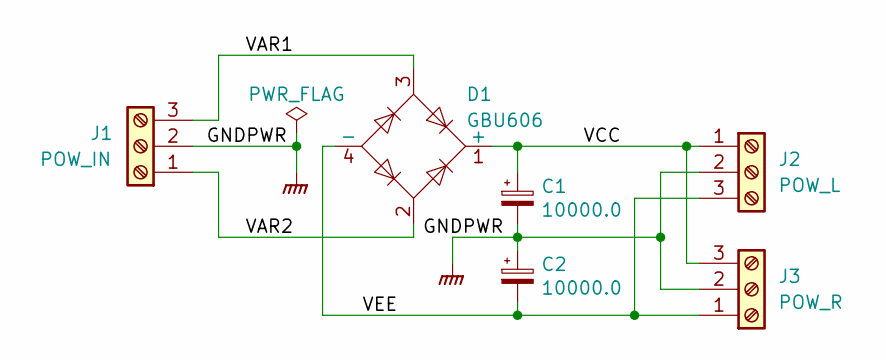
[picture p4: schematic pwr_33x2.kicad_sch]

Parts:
C1, C2: 10000.0; CP_Radial_D25.0mm_P10.00mm_SnapIn
D1: GBU606; Diode_Bridge_Vishay_GBU
J1: POW_IN; TerminalBlock_bornier-3_P5.08mm
J2: POW_L; TerminalBlock_bornier-3_P5.08mm
J3: POW_R; TerminalBlock_bornier-3_P5.08mm

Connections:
/VAR1: D1.3, J1.3
/VAR2: D1.2, J1.1
/VCC: C1.1, D1.1 (+), J2.1, J3.3
/VEE: C2.2, D1.4 (-), J2.3, J3.1
GNDPWR: C1.2, C2.1, J1.2, J2.2, J3.2

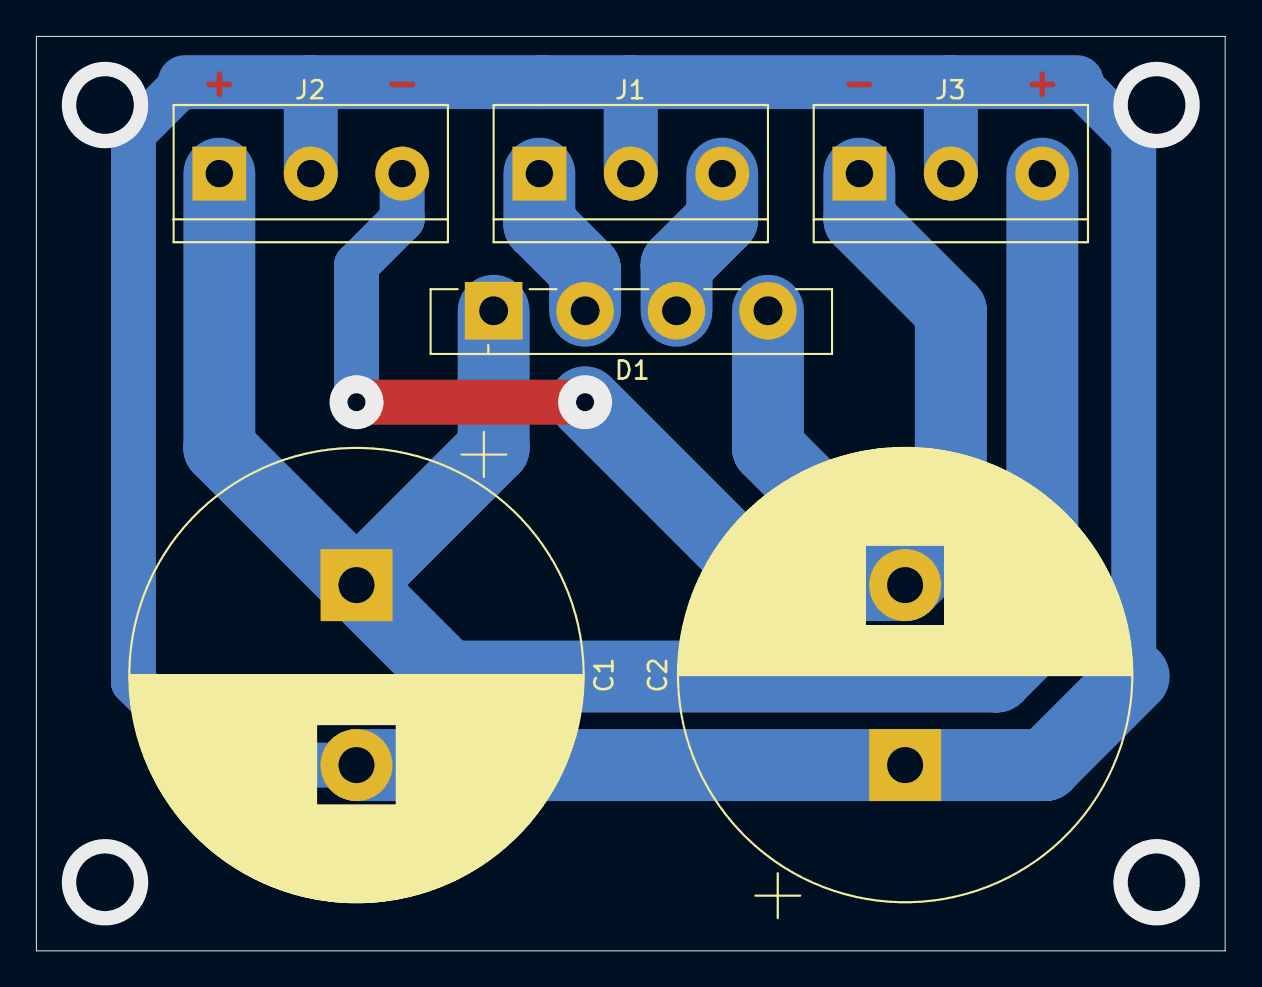
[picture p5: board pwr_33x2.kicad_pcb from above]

Board: 2 copper layers, 66.0 x 50.8 mm, 6 parts (0 on the bottom side), 5 nets.

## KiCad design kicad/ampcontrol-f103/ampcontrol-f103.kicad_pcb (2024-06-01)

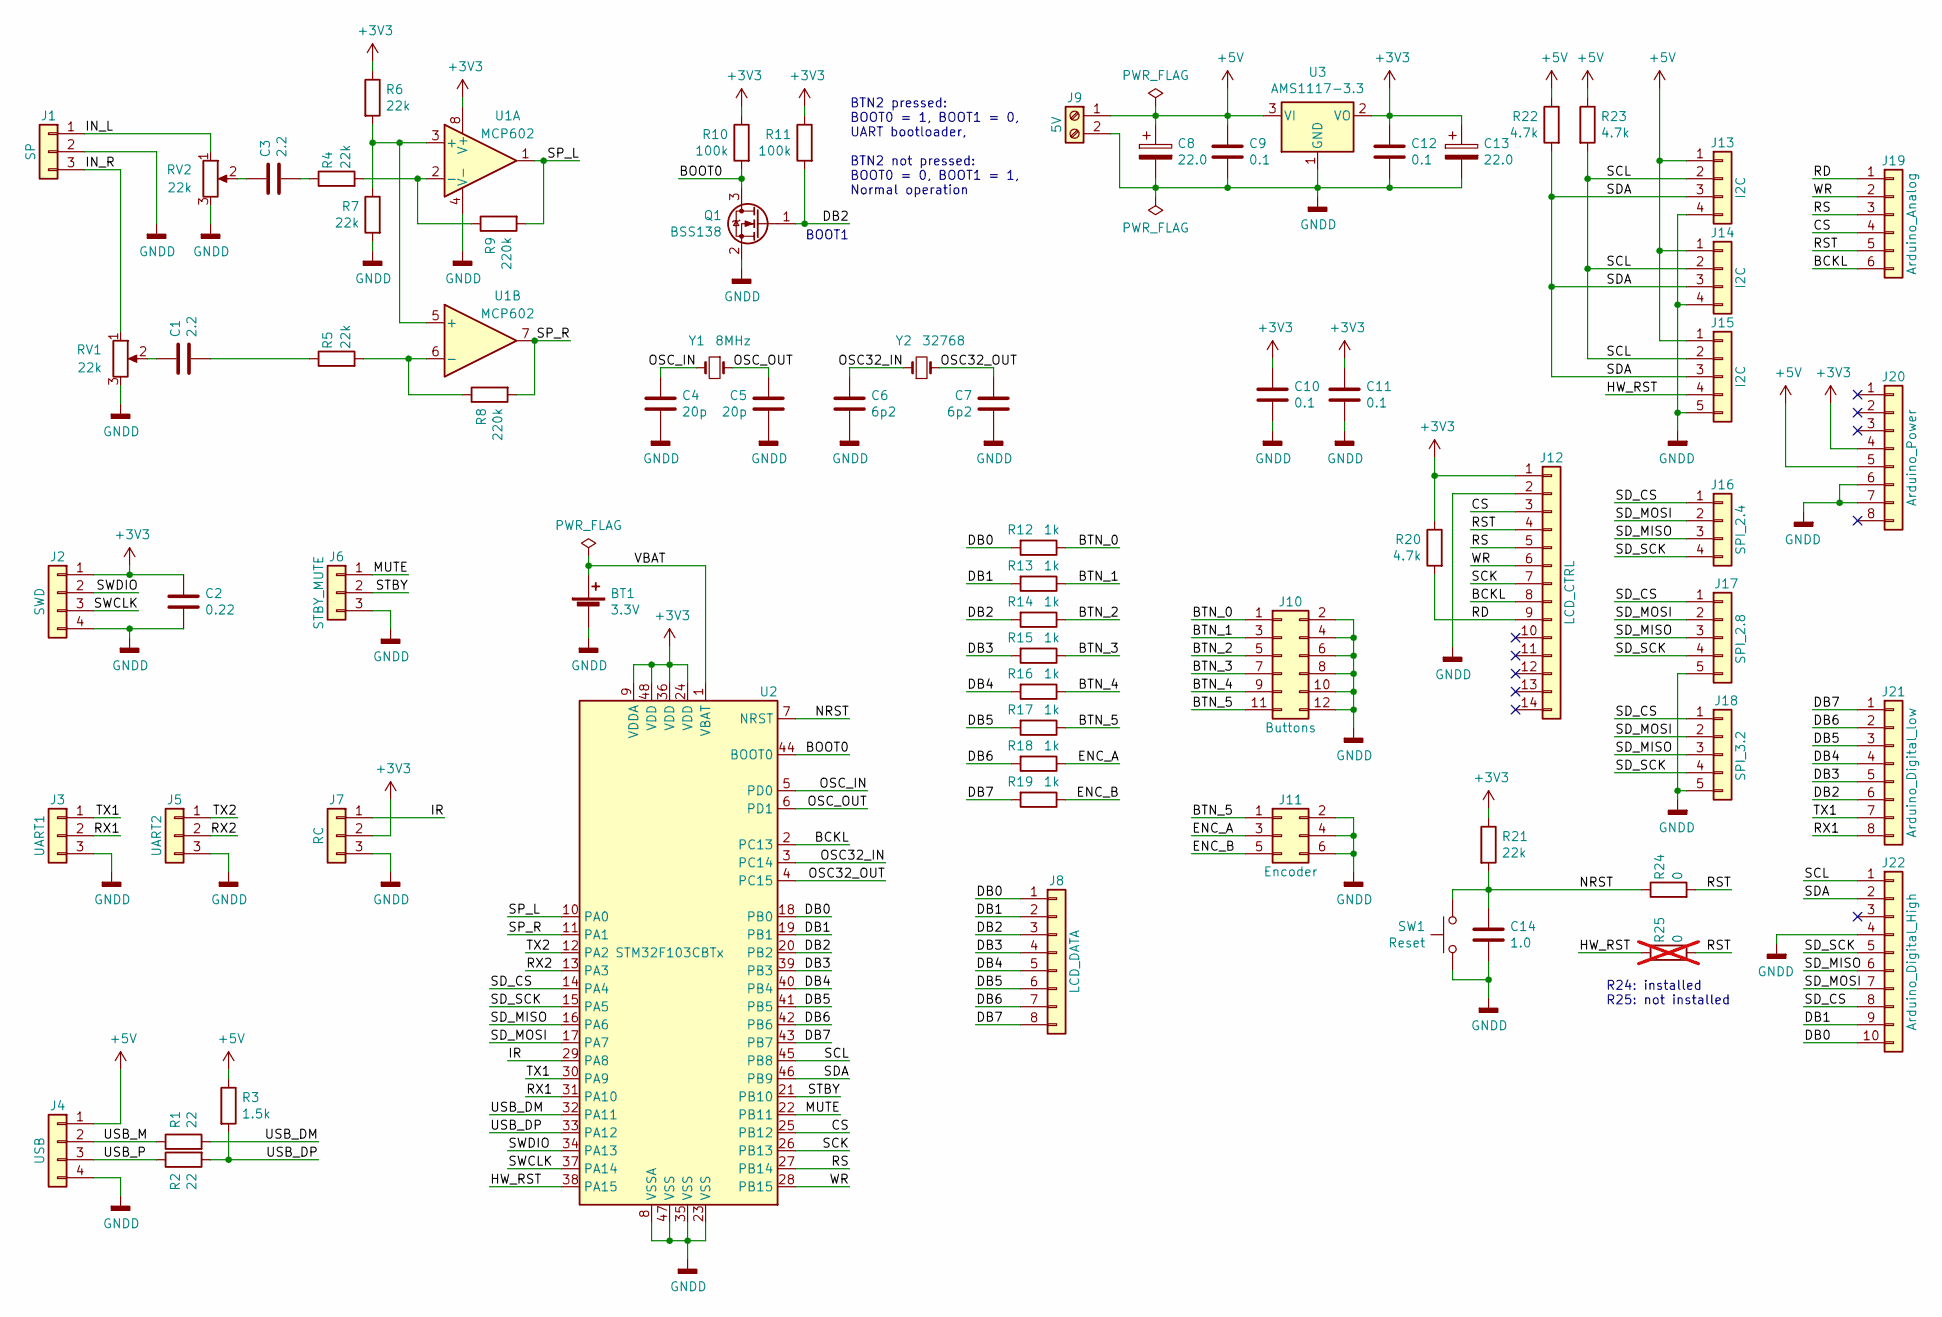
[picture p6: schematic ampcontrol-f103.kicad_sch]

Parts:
BT1: 3.3V; CR1220
C1, C3: 2.2; C_0805_2012Metric
C2: 0.22; C_0805_2012Metric
C4, C5: 20p; C_0805_2012Metric
C6, C7: 6p2; C_0805_2012Metric
C8, C13: 22.0; CP_EIA-6032-28_Kemet-C
C9, C10, C11, C12: 0.1; C_0805_2012Metric
C14: 1.0; C_0805_2012Metric
J1: SP; PinHeader_1x03_P2.54mm_Vertical
J2: SWD; PinHeader_1x04_P2.54mm_Vertical
J3: UART1; PinHeader_1x03_P2.54mm_Vertical
J4: USB; PinHeader_1x04_P2.54mm_Vertical
J5: UART2; PinHeader_1x03_P2.54mm_Vertical
J6: STBY_MUTE; PinHeader_1x03_P2.54mm_Vertical
J7: RC; PinHeader_1x03_P2.54mm_Vertical
J8: LCD_DATA; PinSocket_1x08_P2.54mm_Vertical
J9: 5V; TerminalBlock_bornier-2_P5.08mm
J10: Buttons; PinHeader_2x06_P2.54mm_Vertical
J11: Encoder; PinHeader_2x03_P2.54mm_Vertical
J12: LCD_CTRL; PinSocket_1x14_P2.54mm_Vertical
J13, J14: I2C; PinHeader_1x04_P2.54mm_Vertical
J15: I2C; PinHeader_1x05_P2.54mm_Vertical
J16: SPI_2.4; PinSocket_1x04_P2.54mm_Vertical
J17: SPI_2.8; PinSocket_1x05_P2.54mm_Vertical
J18: SPI_3.2; PinSocket_1x05_P2.54mm_Vertical
J19: Arduino_Analog; PinSocket_1x06_P2.54mm_Vertical
J20: Arduino_Power; PinSocket_1x08_P2.54mm_Vertical
J21: Arduino_Digital_low; PinSocket_1x08_P2.54mm_Vertical
J22: Arduino_Digital_High; PinSocket_1x10_P2.54mm_Vertical
Q1: BSS138; SOT-23
R1, R2: 22; R_0805_2012Metric
R3: 1.5k; R_0805_2012Metric
R4, R5, R6, R7, R21: 22k; R_0805_2012Metric
R8, R9: 220k; R_0805_2012Metric
R10, R11: 100k; R_0805_2012Metric
R12, R13, R14, R15, R16, R17, R18, R19: 1k; R_0805_2012Metric
R20, R22, R23: 4.7k; R_0805_2012Metric
R24: 0; R_0805_2012Metric
R25: 0; R_0805_2012Metric; not fitted
RV1, RV2: 22k; Potentiometer_Piher_PT-6-V_Vertical
SW1: Reset; SW_PUSH_6mm
U1: MCP602; SOIC-8_3.9x4.9mm_P1.27mm
U2: STM32F103CBTx; LQFP-48_7x7mm_P0.5mm
U3: AMS1117-3.3; SOT-223-3_TabPin2
Y1: 8MHz; Crystal_HC49-4H_Vertical
Y2: 32768; Crystal_C38-LF_D3.0mm_L8.0mm_Vertical

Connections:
+3V3: C2.1, C10.2, C11.2, C12.2, C13.1, J2.1, J7.2, J12.1, J20.4, R6.1, R10.1, R11.1, R20.1, R21.1, U1.8 (V+), U2.9 (VDDA), U2.24 (VDD), U2.36 (VDD), U2.48 (VDD), U3.2 (VO)
+5V: C8.1, C9.2, J4.1, J9.1, J13.1, J14.1, J15.1, J20.5, R3.1, R22.1, R23.1, U3.3 (VI)
/BCKL: J12.8, J19.6, U2.2 (PC13)
/BOOT0: Q1.3 (D), R10.2, U2.44 (BOOT0)
/BTN_0: J10.1, R12.1
/BTN_1: J10.3, R13.1
/BTN_2: J10.5, R14.1
/BTN_3: J10.7, R15.1
/BTN_4: J10.9, R16.1
/BTN_5: J10.11, J11.1, R17.1
/CS: J12.3, J19.4, U2.25 (PB12)
/DB0: J8.1, J22.10, R12.2, U2.18 (PB0)
/DB1: J8.2, J22.9, R13.2, U2.19 (PB1)
/DB2: J8.3, J21.6, Q1.1 (G), R11.2, R14.2, U2.20 (PB2)
/DB3: J8.4, J21.5, R15.2, U2.39 (PB3)
/DB4: J8.5, J21.4, R16.2, U2.40 (PB4)
/DB5: J8.6, J21.3, R17.2, U2.41 (PB5)
/DB6: J8.7, J21.2, R18.2, U2.42 (PB6)
/DB7: J8.8, J21.1, R19.2, U2.43 (PB7)
/ENC_A: J11.3, R18.1
/ENC_B: J11.5, R19.1
/HW_RST: J15.4, R25.1, U2.38 (PA15)
/IN_L: J1.1, RV2.1
/IN_R: J1.3, RV1.1
/IR: J7.1, U2.29 (PA8)
/MUTE: J6.1, U2.22 (PB11)
/NRST: C14.2, R21.2, R24.1, SW1.1, U2.7 (NRST)
/OSC32_IN: C6.1, U2.3 (PC14), Y2.1
/OSC32_OUT: C7.2, U2.4 (PC15), Y2.2
/OSC_IN: C4.1, U2.5 (PD0), Y1.2
/OSC_OUT: C5.2, U2.6 (PD1), Y1.1
/RD: J12.9, J19.1, R20.2
/RS: J12.5, J19.3, U2.27 (PB14)
/RST: J12.4, J19.5, R24.2, R25.2
/RX1: J3.2, J21.8, U2.31 (PA10)
/RX2: J5.2, U2.13 (PA3)
/SCK: J12.7, U2.26 (PB13)
/SCL: J13.2, J14.2, J15.2, J22.1, R23.2, U2.45 (PB8)
/SDA: J13.3, J14.3, J15.3, J22.2, R22.2, U2.46 (PB9)
/SD_CS: J16.1, J17.1, J18.1, J22.8, U2.14 (PA4)
/SD_MISO: J16.3, J17.3, J18.3, J22.6, U2.16 (PA6)
/SD_MOSI: J16.2, J17.2, J18.2, J22.7, U2.17 (PA7)
/SD_SCK: J16.4, J17.4, J18.4, J22.5, U2.15 (PA5)
/SP_L: R9.2, U1.1, U2.10 (PA0)
/SP_R: R8.2, U1.7, U2.11 (PA1)
/STBY: J6.2, U2.21 (PB10)
/SWCLK: J2.3, U2.37 (PA14)
/SWDIO: J2.2, U2.34 (PA13)
/TX1: J3.1, J21.7, U2.30 (PA9)
/TX2: J5.1, U2.12 (PA2)
/USB_DM: R1.2, U2.32 (PA11)
/USB_DP: R2.2, R3.2, U2.33 (PA12)
/USB_M: J4.2, R1.1
/USB_P: J4.3, R2.1
/VBAT: BT1.1 (+), U2.1 (VBAT)
/WR: J12.6, J19.2, U2.28 (PB15)
GNDD: BT1.2 (-), C2.2, C4.2, C5.1, C6.2, C7.1, C8.2, C9.1, C10.1, C11.1, C12.1, C13.2, C14.1, J1.2, J2.4, J3.3, J4.4, J5.3, J6.3, J7.3, J9.2, J10.2, J10.4, J10.6, J10.8, J10.10, J10.12, J11.2, J11.4, J11.6, J12.2, J13.4, J14.4, J15.5, J17.5, J18.5, J20.6, J20.7, J22.4, Q1.2 (S), R7.2, RV1.3, RV2.3, SW1.2, U1.4 (V-), U2.8 (VSSA), U2.23 (VSS), U2.35 (VSS), U2.47 (VSS), U3.1 (GND)
unnamed: C1.1, R5.1
unnamed: C1.2, RV1.2
unnamed: C3.1, R4.1
unnamed: C3.2, RV2.2
unnamed: R4.2, R9.1, U1.2 (-)
unnamed: R5.2, R8.1, U1.6 (-)
unnamed: R6.2, R7.1, U1.3 (+), U1.5 (+)

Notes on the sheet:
R24: installed R25: not installed
BOOT1
BTN2 pressed: BOOT0 = 1, BOOT1 = 0, UART bootloader, BTN2 not pressed: BOOT0 = 0, BOOT1 = 1, Normal operation

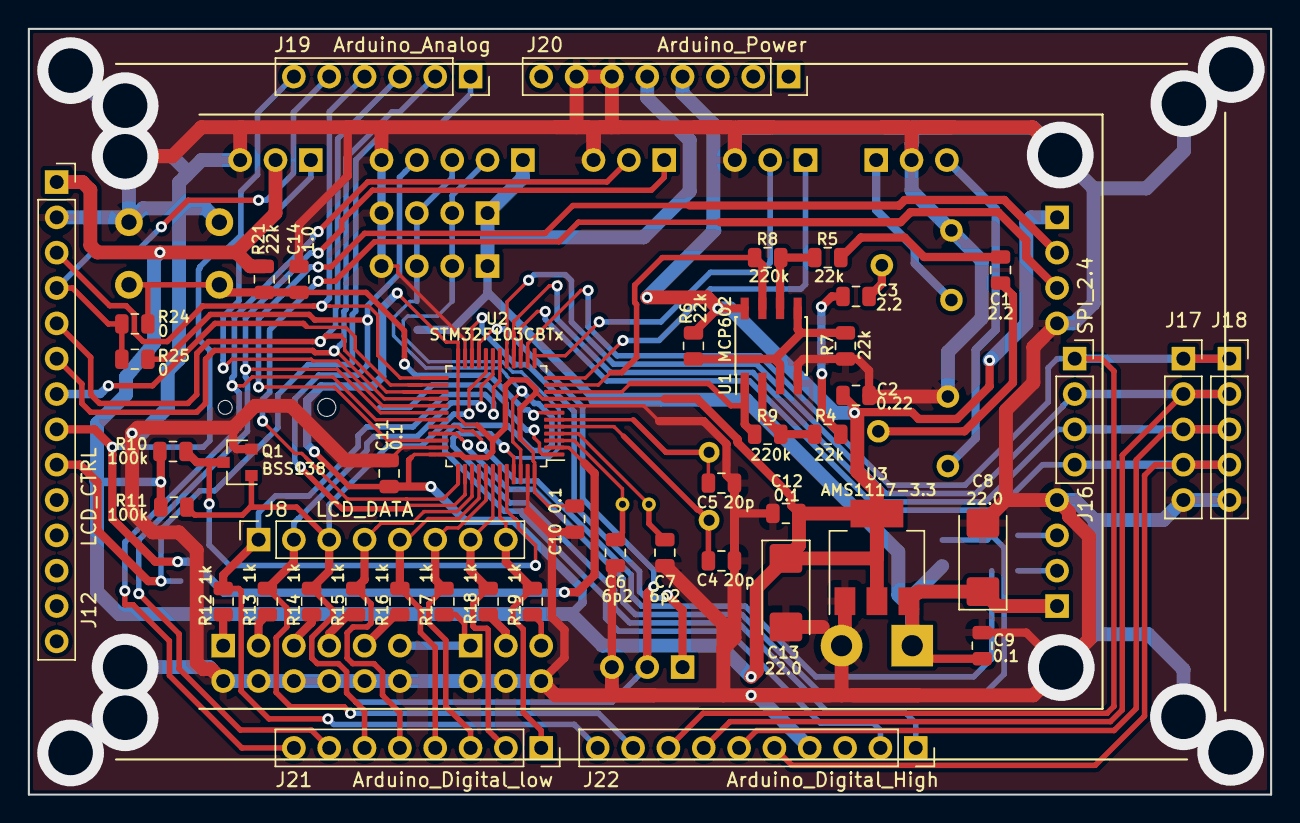
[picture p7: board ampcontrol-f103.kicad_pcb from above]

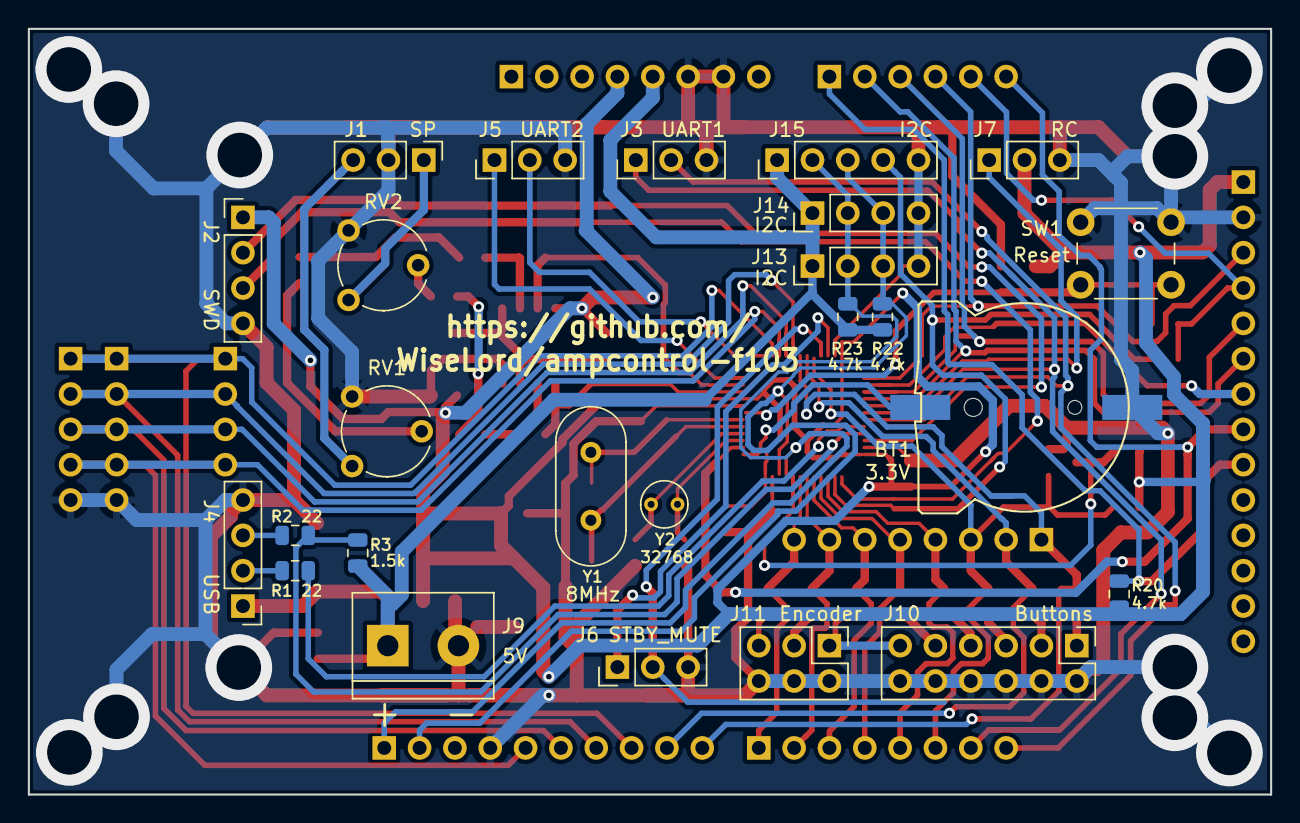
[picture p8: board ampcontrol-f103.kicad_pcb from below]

Board: 2 copper layers, 89.3 x 55.0 mm, 71 parts (25 on the bottom side), 64 nets.

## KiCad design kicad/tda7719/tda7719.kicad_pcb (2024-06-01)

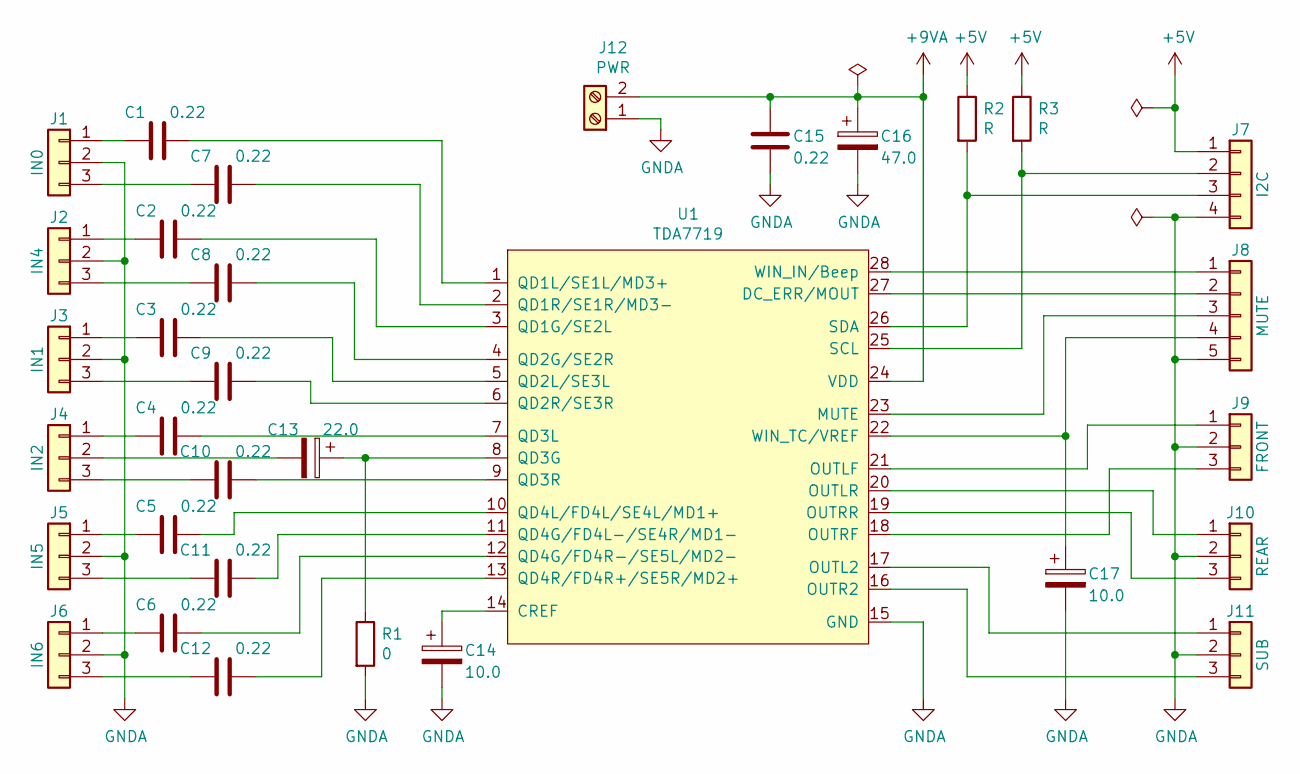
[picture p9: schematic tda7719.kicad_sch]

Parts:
C1, C2, C3, C4, C5, C6, C7, C8, C9, C10, C11, C12, C15: 0.22; C_1206_3216Metric_Pad1.42x1.75mm_HandSolder
C13: 22.0; CP_Radial_D5.0mm_P2.50mm
C14, C17: 10.0; CP_Radial_D5.0mm_P2.50mm
C16: 47.0; CP_Radial_D5.0mm_P2.50mm
J1: IN0; PinHeader_1x03_P2.54mm_Vertical
J2: IN4; PinHeader_1x03_P2.54mm_Vertical
J3: IN1; PinHeader_1x03_P2.54mm_Vertical
J4: IN2; PinHeader_1x03_P2.54mm_Vertical
J5: IN5; PinHeader_1x03_P2.54mm_Vertical
J6: IN6; PinHeader_1x03_P2.54mm_Vertical
J7: I2C; PinHeader_1x04_P2.54mm_Vertical
J8: MUTE; PinHeader_1x05_P2.54mm_Vertical
J9: FRONT; PinHeader_1x03_P2.54mm_Vertical
J10: REAR; PinHeader_1x03_P2.54mm_Vertical
J11: SUB; PinHeader_1x03_P2.54mm_Vertical
J12: PWR; TerminalBlock_Phoenix_MKDS-1,5-2-5.08_1x02_P5.08mm_Horizont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
R1: 0; R_1206_3216Metric_Pad1.42x1.75mm_HandSolder
R2, R3: R; R_1206_3216Metric_Pad1.42x1.75mm_HandSolder
U1: TDA7719; TSSOP-28_4.4x9.7mm_P0.65mm

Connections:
+5V: J7.1, R2.1, R3.1
+9VA: C15.2, C16.1, J12.2, U1.24 (VDD)
GNDA: C14.2, C15.1, C16.2, C17.2, J1.2, J2.2, J3.2, J5.2, J6.2, J7.4, J8.5, J9.2, J10.2, J11.2, J12.1, R1.2, U1.15 (GND)
unnamed: C1.1, U1.1 (QD1L/SE1L/MD3+)
unnamed: C1.2, J1.1
unnamed: C2.1, U1.3 (QD1G/SE2L)
unnamed: C2.2, J2.1
unnamed: C3.1, U1.5 (QD2L/SE3L)
unnamed: C3.2, J3.1
unnamed: C4.1, U1.7 (QD3L)
unnamed: C4.2, J4.1
unnamed: C5.1, U1.10 (QD4L/FD4L/SE4L/MD1+)
unnamed: C5.2, J5.1
unnamed: C6.1, U1.12 (QD4G/FD4R-/SE5L/MD2-)
unnamed: C6.2, J6.1
unnamed: C7.1, U1.2 (QD1R/SE1R/MD3-)
unnamed: C7.2, J1.3
unnamed: C8.1, U1.4 (QD2G/SE2R)
unnamed: C8.2, J2.3
unnamed: C9.1, U1.6 (QD2R/SE3R)
unnamed: C9.2, J3.3
unnamed: C10.1, U1.9 (QD3R)
unnamed: C10.2, J4.3
unnamed: C11.1, U1.11 (QD4G/FD4L-/SE4R/MD1-)
unnamed: C11.2, J5.3
unnamed: C12.1, U1.13 (QD4R/FD4R+/SE5R/MD2+)
unnamed: C12.2, J6.3
unnamed: C13.1, R1.1, U1.8 (QD3G)
unnamed: C13.2, J4.2
unnamed: C14.1, U1.14 (CREF)
unnamed: C17.1, J8.4, U1.22 (WIN_TC/VREF)
unnamed: J7.2, R3.2, U1.25 (SCL)
unnamed: J7.3, R2.2, U1.26 (SDA)
unnamed: J8.1, U1.28 (WIN_IN/Beep)
unnamed: J8.2, U1.27 (DC_ERR/MOUT)
unnamed: J8.3, U1.23 (MUTE)
unnamed: J9.1, U1.21 (OUTLF)
unnamed: J9.3, U1.18 (OUTRF)
unnamed: J10.1, U1.20 (OUTLR)
unnamed: J10.3, U1.19 (OUTRR)
unnamed: J11.1, U1.17 (OUTL2)
unnamed: J11.3, U1.16 (OUTR2)

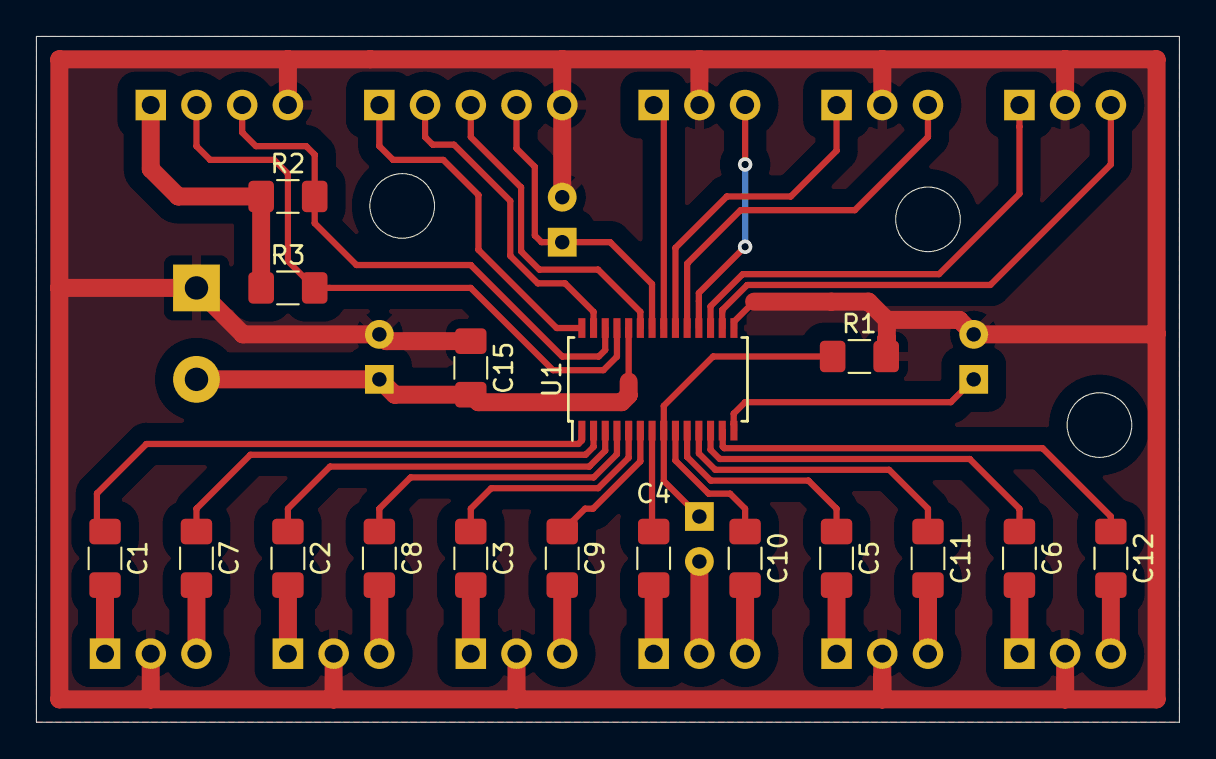
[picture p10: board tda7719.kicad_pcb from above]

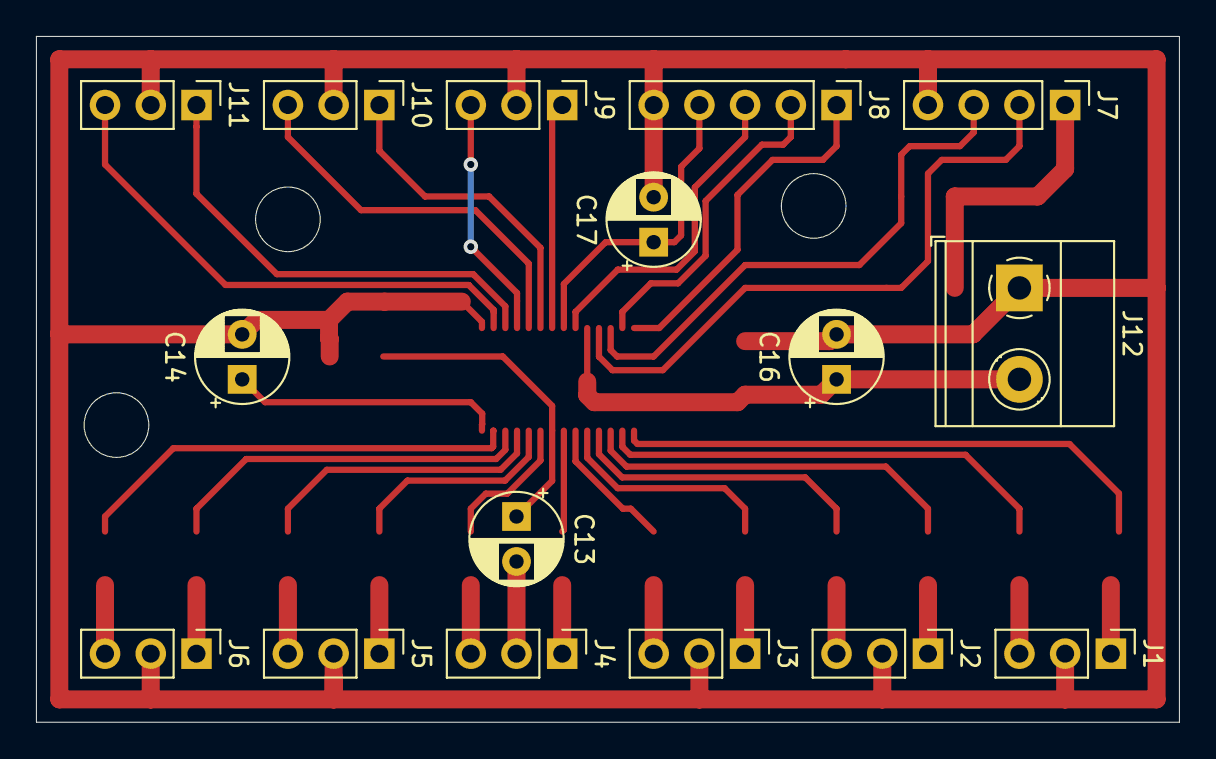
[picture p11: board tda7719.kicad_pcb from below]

Board: 2 copper layers, 63.5 x 38.1 mm, 33 parts (16 on the bottom side), 42 nets.

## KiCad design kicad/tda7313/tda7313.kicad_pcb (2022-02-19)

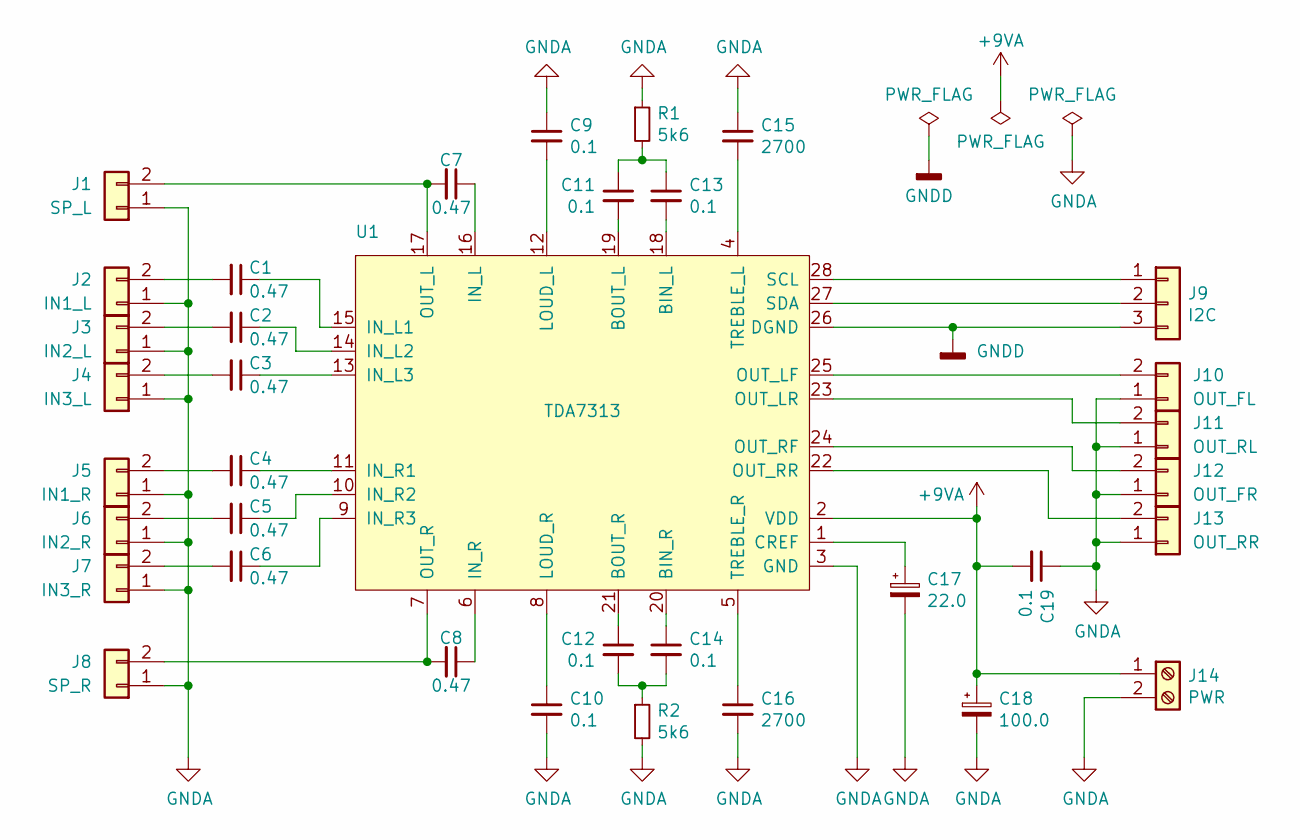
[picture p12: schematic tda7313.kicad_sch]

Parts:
C1, C2, C3, C4, C5, C6, C7, C8: 0.47; C_Rect_L13.0mm_W8.0mm_P10.00mm_FKS3_FKP3_MKS4
C9, C10, C11, C12, C13, C14: 0.1; C_Rect_L13.0mm_W4.0mm_P10.00mm_FKS3_FKP3_MKS4
C15, C16: 2700; C_Disc_D4.7mm_W2.5mm_P5.00mm
C17: 22.0; CP_Radial_D6.3mm_P2.50mm
C18: 100.0; CP_Radial_D6.3mm_P2.50mm
C19: 0.1; C_1206_3216Metric_Pad1.42x1.75mm_HandSolder
J1: SP_L; PinHeader_1x02_P2.54mm_Vertical
J2: IN1_L; PinHeader_1x02_P2.54mm_Vertical
J3: IN2_L; PinHeader_1x02_P2.54mm_Vertical
J4: IN3_L; PinHeader_1x02_P2.54mm_Vertical
J5: IN1_R; PinHeader_1x02_P2.54mm_Vertical
J6: IN2_R; PinHeader_1x02_P2.54mm_Vertical
J7: IN3_R; PinHeader_1x02_P2.54mm_Vertical
J8: SP_R; PinHeader_1x02_P2.54mm_Vertical
J9: I2C; PinHeader_1x03_P2.54mm_Vertical
J10: OUT_FL; PinHeader_1x02_P2.54mm_Vertical
J11: OUT_RL; PinHeader_1x02_P2.54mm_Vertical
J12: OUT_FR; PinHeader_1x02_P2.54mm_Vertical
J13: OUT_RR; PinHeader_1x02_P2.54mm_Vertical
J14: PWR; TerminalBlock_Phoenix_MKDS-1,5-2-5.08_1x02_P5.08mm_Horizont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
R1, R2: 5k6; R_1206_3216Metric_Pad1.42x1.75mm_HandSolder
U1: TDA7313; SOIC-28W_7.5x17.9mm_P1.27mm

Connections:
+9VA: C18.1, C19.2, J14.1, U1.2 (VDD)
GNDA: C9.1, C10.2, C15.1, C16.2, C17.2, C18.2, C19.1, J1.1, J2.1, J3.1, J4.1, J5.1, J6.1, J7.1, J8.1, J10.1, J11.1, J12.1, J13.1, J14.2, R1.1, R2.2, U1.3 (GND)
GNDD: J9.3, U1.26 (DGND)
unnamed: C1.1, U1.15 (IN_L1)
unnamed: C1.2, J2.2
unnamed: C2.1, U1.14 (IN_L2)
unnamed: C2.2, J3.2
unnamed: C3.1, U1.13 (IN_L3)
unnamed: C3.2, J4.2
unnamed: C4.1, U1.11 (IN_R1)
unnamed: C4.2, J5.2
unnamed: C5.1, U1.10 (IN_R2)
unnamed: C5.2, J6.2
unnamed: C6.1, U1.9 (IN_R3)
unnamed: C6.2, J7.2
unnamed: C7.1, U1.16 (IN_L)
unnamed: C7.2, J1.2, U1.17 (OUT_L)
unnamed: C8.1, U1.6 (IN_R)
unnamed: C8.2, J8.2, U1.7 (OUT_R)
unnamed: C9.2, U1.12 (LOUD_L)
unnamed: C10.1, U1.8 (LOUD_R)
unnamed: C11.1, C13.1, R1.2
unnamed: C11.2, U1.19 (BOUT_L)
unnamed: C12.1, U1.21 (BOUT_R)
unnamed: C12.2, C14.2, R2.1
unnamed: C13.2, U1.18 (BIN_L)
unnamed: C14.1, U1.20 (BIN_R)
unnamed: C15.2, U1.4 (TREBLE_L)
unnamed: C16.1, U1.5 (TREBLE_R)
unnamed: C17.1, U1.1 (CREF)
unnamed: J9.1, U1.28 (SCL)
unnamed: J9.2, U1.27 (SDA)
unnamed: J10.2, U1.25 (OUT_LF)
unnamed: J11.2, U1.23 (OUT_LR)
unnamed: J12.2, U1.24 (OUT_RF)
unnamed: J13.2, U1.22 (OUT_RR)



Board: 2 copper layers, 68.6 x 55.9 mm, 36 parts (4 on the bottom side), 36 nets.

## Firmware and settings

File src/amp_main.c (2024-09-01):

#include "amp.h"

#include <stddef.h>

#include "audio/audio.h"
#include "bt.h"
#include "gui/canvas.h"
#include "i2c.h"
#include "i2cexp.h"
#include "input.h"
#include "mpc.h"
#include "menu.h"
#include "pins.h"
#include "rc.h"
#include "rtc.h"
#include "settings.h"
#include "spectrum.h"
#include "swtimers.h"
#include "timers.h"
#include "tr/labels.h"
#include "tuner/rds/demod.h"
#include "tuner/rds/parser.h"
#include "tuner/stations.h"
#include "tuner/tuner.h"
#include "utils.h"

#ifdef _ENABLE_USB
#include "usb/hidkeys.h"
#include "usb/usbhid.h"
#endif

#define SW_TIM_SCREENSAVER_GAP      20
#define SW_TIM_SILENCE_SHOW_GAP     30
#define SW_TIM_STBY_SHOW_GAP        60

#define S_TO_MS(x)                  ((x) * 1000 + 999)

typedef struct {
    Icon iconHint;

    bool screenClear;
    ScreenType screenNext;

    uint8_t inputStatus;
    int8_t volume;

    int8_t brightness;
    uint8_t signalCnt;

    AudioTune tune;
    AudioTune flag;
} AmpPriv;

static void actionGetRemote(void);
static void actionGetTimers(void);

static void actionRemapBtnShort(void);
static void actionRemapBtnLong(void);
static void actionRemapRemote(void);
static void actionRemapCommon(void);
static void actionRemapNavigate(void);
static void actionRemapEncoder(void);

static void ampSendMediaKey(MediaKey key);

static const InputType ampInDefault[MAX_INPUTS] = {
    IN_PC,
    IN_AUX,
    IN_AUX,
    IN_KARADIO,
    IN_TUNER,
    IN_BLUETOOTH,
    IN_DISABLED,
    IN_DISABLED,
};

static AmpPriv priv = {
    .inputStatus = 0x00,
    .volume = 0,
    .screenClear = true,
    .screenNext = SCREEN_STANDBY,
};
static Amp *amp;

static Action action = {
    .type = ACTION_NONE,
    .value = FLAG_ENTER,
};

static void actionSet(ActionType type, int16_t value)
{
    action.type = type;
    action.value = value;
}

static void screenSet(ScreenType type, int16_t timeout)
{
    priv.screenNext = type;
    swTimSet(SW_TIM_DISPLAY, timeout);
}

static void rdsParserCb(void)
{
    swTimSet(SW_TIM_RDS_HOLD, 1000);
}

static bool screenCheckClear(void)
{
    bool clear = false;

    if (priv.screenClear) {
        clear = true;
        priv.screenClear = false;
    } else if (amp->screen != priv.screenNext) {
        clear = true;
        switch (amp->screen) {
        case SCREEN_STANDBY:
        case SCREEN_TIME:
            if (priv.screenNext == SCREEN_STANDBY || priv.screenNext == SCREEN_TIME) {
                clear = false;
            }
            break;
        case SCREEN_MENU:
            menuGet()->selected = 0;
            break;
        default:
            break;
        }
    }

    if (amp->screen != priv.screenNext || clear) {
        // Handle standby/work brightness
        ampSetBrightness(priv.screenNext == SCREEN_STANDBY ? amp->brStby : amp->brWork);
    }

    // Save current screen and screen parameter
    amp->screen = priv.screenNext;

    return clear;
}

static void ampScreenPwm(void)
{
    static int8_t br;

    if (++br >= LCD_BR_MAX) {
        br = 0;
    }

    if (br == priv.brightness) {
        glcdSetBacklight(false);
    } else if (br == 0) {
        glcdSetBacklight(true);
    }
}

static ScreenType getScrDef(void)
{
    AudioProc *aProc = audioGet();

    int32_t swTimStby = swTimGet(SW_TIM_STBY);
    int32_t swTimSilence = swTimGet(SW_TIM_SILENCE);


    if (swTimStby > 0 && swTimStby < swTimSilence) {
        if (swTimStby < S_TO_MS(SW_TIM_STBY_SHOW_GAP)) {
            return SCREEN_STBY_TIMER;
        }
    }

    if (swTimSilence > 0) {
        int16_t min = amp->silenceTimer;
        if (min <= 0) {
            min = 32767;
        }
        if (swTimSilence < S_TO_MS(SW_TIM_SILENCE_SHOW_GAP)) {
            return SCREEN_SILENCE_TIMER;
        } else if (swTimSilence < S_TO_MS(60 * min - SW_TIM_SCREENSAVER_GAP)) {
            if (amp->scrSaver) {
                return SCREEN_SAVER;
            }
        }
    }

    if (aProc->par.flags & AUDIO_FLAG_MUTE) {
        return SCREEN_AUDIO_INPUT;
    }

    return amp->defScreen;
}

static void actionDispExpired(void)
{
    ScreenType scrDef = getScrDef();

    priv.iconHint = ICON_EMPTY;
    ScreenType scrMode = amp->screen;

    rtcSetMode(RTC_NOEDIT);
    priv.tune = AUDIO_TUNE_VOLUME;

    if (amp->status != AMP_STATUS_STBY) {
        if (scrMode != scrDef) {
            screenSet(scrDef, -1);
        }
    } else {
        screenSet(SCREEN_STANDBY, -1);
    }
}

static void actionResetSilenceTimer(void)
{
    int16_t min = amp->silenceTimer;
    if (min <= 0) {
        min = 32767;
    }

    if (min) {
        swTimSet(SW_TIM_SILENCE, S_TO_MS(60 * min));
    }
}

static void inputDisable(void)
{
    AudioProc *aProc = audioGet();
    InputType inType = amp->inType[aProc->par.input];

    switch (inType) {
    case IN_TUNER:
        swTimSet(SW_TIM_RDS_HOLD, SW_TIM_OFF);
        tunerSetPower(false);
        break;
    case IN_KARADIO:
    case IN_BLUETOOTH:
        ampSendMediaKey(MEDIAKEY_STOP);
        break;
    default:
        break;
    }

    // TODO: Power off current input device
}

static void inputEnable(void)
{
    Tuner *tuner = tunerGet();
    AudioProc *aProc = audioGet();
    InputType inType = amp->inType[aProc->par.input];

    switch (inType) {
    case IN_TUNER:
        swTimSet(SW_TIM_RDS_HOLD, SW_TIM_OFF);
        tunerSetPower(true);
        tunerSetVolume(tuner->par.volume);
        tunerSetMute(false);
        tunerSetFreq(tuner->status.freq);
        break;
    case IN_MPD:
    case IN_KARADIO:
        ampSendMediaKey(MEDIAKEY_PLAY);
        mpcSyncRequest();
        break;
    default:
        break;
    }
}

static void inputSetPower(bool value)
{
    AudioProc *aProc = audioGet();
    int8_t input = aProc->par.input;

    if (value) {
        priv.inputStatus = (uint8_t)(1 << input);
    } else {
        priv.inputStatus = 0x00;
    }

    I2cAddrIdx i2cAddrIdx = i2cExpGet()->idxInStatus;

    if (i2cAddrIdx != I2C_ADDR_DISABLED) {
        if (!i2cIsEnabled(I2C_AMP)) {
            i2cInit(I2C_AMP, 100000, 0x00);
            i2cExpSend(i2cAddrIdx, priv.inputStatus);
            i2cDeInit(I2C_AMP);
        } else {
            i2cExpSend(i2cAddrIdx, priv.inputStatus);
        }
    }
}

void ampPinMute(bool value)
{
    if (amp->muteLow) {
        if (value) {
            SET(MUTE);
        } else {
            CLR(MUTE);
        }
    } else {
        if (value) {
            CLR(MUTE);
        } else {
            SET(MUTE);
        }
    }
}

void ampPinStby(bool value)
{
    if (amp->stbyLow) {
        if (value) {
            SET(STBY);
        } else {
            CLR(STBY);
        }
    } else {
        if (value) {
            CLR(STBY);
        } else {
            SET(STBY);
        }
    }
}

static void ampMute(bool value)
{
    AudioProc *aProc = audioGet();
    const AudioGrid *grid = aProc->par.grid[AUDIO_TUNE_VOLUME];

    if (value) {
        swTimSet(SW_TIM_SOFT_VOLUME, SW_TIM_OFF);
    } else {
        audioSetTune(AUDIO_TUNE_VOLUME, grid->min);
        swTimSet(SW_TIM_SOFT_VOLUME, SW_TIM_ON);
    }

    ampPinMute(value);
    audioSetFlag(AUDIO_FLAG_MUTE, value);
}

static void ampReadSettings(void)
{
    amp->brStby = settingsRead(PARAM_DISPLAY_BR_STBY, 3);
    amp->brWork = settingsRead(PARAM_DISPLAY_BR_WORK, LCD_BR_MAX);
    amp->defScreen = settingsRead(PARAM_DISPLAY_DEF, SCREEN_AUDIO_INPUT);
    amp->scrSaver = settingsRead(PARAM_DISPLAY_SCRSAVER, true);
    amp->silenceTimer = settingsRead(PARAM_SYSTEM_SIL_TIM, 5);
    amp->stbyLow = settingsRead(PARAM_SYSTEM_STBY_LOW, false);
    amp->muteLow = settingsRead(PARAM_SYSTEM_MUTE_LOW, false);
    amp->showDb = settingsRead(PARAM_AUDIO_SHOWDB, true);

    for (uint8_t i = 0; i < MAX_INPUTS; i++) {
        amp->inType[i] = settingsRead(PARAM_AUDIO_IN0 + i, ampInDefault[i]);
    }

    audioReadSettings(AUDIO_IC_TDA7439);
    tunerReadSettings(TUNER_IC_RDA5807);
}

static void ampVolumeInit(void)
{
    AudioProc *aProc = audioGet();
    const AudioGrid *grid = aProc->par.grid[AUDIO_TUNE_VOLUME];
    int8_t *volItem = &aProc->par.tune[AUDIO_TUNE_VOLUME];

    priv.volume = *volItem;
    *volItem = grid->min;
}

static void ampExitStby(void)
{
    swTimSet(SW_TIM_MPD_POWEROFF, SW_TIM_OFF);

    ampReadSettings();

    ampPinStby(false);      // Power on amplifier

    inputSetPower(true);    // Power on input device

    amp->status = AMP_STATUS_POWERED;

    swTimSet(SW_TIM_AMP_INIT, 600);
    swTimSet(SW_TIM_SP_CONVERT, SW_TIM_ON);
    swTimSet(SW_TIM_CHECK_SIGNAL, SW_TIM_ON);
}

static void ampEnterStby(void)
{
    swTimSet(SW_TIM_MPD_POWEROFF, 60000); // Turn off MPD after 60 seconds
    mpcSendMediaKey(MEDIAKEY_STOP);

    swTimSet(SW_TIM_STBY, SW_TIM_OFF);
    swTimSet(SW_TIM_SILENCE, SW_TIM_OFF);
    swTimSet(SW_TIM_INPUT_POLL, SW_TIM_OFF);
    swTimSet(SW_TIM_SP_CONVERT, SW_TIM_OFF);
    swTimSet(SW_TIM_CHECK_SIGNAL, SW_TIM_OFF);

    settingsStore(PARAM_DISPLAY_DEF, amp->defScreen);

    ampMute(true);

    // Restore volume value before saving
    AudioProc *aProc = audioGet();
    int8_t *volItem = &aProc->par.tune[AUDIO_TUNE_VOLUME];
    *volItem = priv.volume;

    audioSetPower(false);

    inputDisable();

    inputSetPower(false);   // Power off input device

    amp->status = AMP_STATUS_STBY;
    swTimSet(SW_TIM_AMP_INIT, 1000);
}

void ampInitHw(void)
{
    swTimSet(SW_TIM_AMP_INIT, SW_TIM_OFF);

    switch (amp->status) {
    case AMP_STATUS_POWERED:
        pinsHwResetI2c();
        i2cInit(I2C_AMP, 100000, 0x00);

        audioInit();
        ampVolumeInit();

        audioSetPower(true);
        ampMute(true);

        swTimSet(SW_TIM_RDS_HOLD, SW_TIM_OFF);
        tunerInit();

        i2cExpInit();

        amp->status = AMP_STATUS_HW_READY;

        swTimSet(SW_TIM_AMP_INIT, 500);
        break;
    case AMP_STATUS_HW_READY:
        inputEnable();

        ampMute(false);

        amp->status = AMP_STATUS_ACTIVE;

        swTimSet(SW_TIM_INPUT_POLL, 100);
        break;
    case AMP_STATUS_STBY:
        swTimSet(SW_TIM_AMP_INIT, SW_TIM_OFF);
        ampPinStby(true);

        break;
    }
}

static void ampSetInput(int8_t value)
{
    swTimSet(SW_TIM_INPUT_POLL, SW_TIM_OFF);

    ampMute(true);

    inputDisable();
    inputSetPower(false);
    audioSetInput(value);
    inputSetPower(true);

    amp->status = AMP_STATUS_HW_READY;
    swTimSet(SW_TIM_AMP_INIT, 400);
}


static void actionNavigateMenu(RcCmd cmd)
{
    Menu *menu = menuGet();

    switch (cmd) {
    case RC_CMD_NAV_OK:
    case RC_CMD_NAV_RIGHT:
        actionSet(ACTION_MENU_SELECT, (int16_t)(menuGetFirstChild()));
        break;
    case RC_CMD_NAV_BACK:
    case RC_CMD_NAV_LEFT:
        if (menu->selected) {
            menu->selected = false;
        } else if (menuIsTop()) {
            // TODO: Return to original screen called menu
            actionSet(ACTION_STANDBY, FLAG_ENTER);
        } else {
            actionSet(ACTION_MENU_SELECT, (int16_t)menu->parent);
        }
        break;
    case RC_CMD_NAV_UP:
    case RC_CMD_CHAN_PREV:
        actionSet(ACTION_MENU_CHANGE, -1);
        break;
    case RC_CMD_NAV_DOWN:
    case RC_CMD_CHAN_NEXT:
        actionSet(ACTION_MENU_CHANGE, +1);
        break;
    }
}

static void actionNavigateTextEdit(RcCmd cmd)
{
    switch (cmd) {
    case RC_CMD_NAV_OK:
        action.type = ACTION_TEXTEDIT_APPLY;
        break;
    case RC_CMD_NAV_BACK:
        action.type = ACTION_TEXTEDIT_CANCEL;
        break;
    case RC_CMD_NAV_RIGHT:
    case RC_CMD_CHAN_NEXT:
        action.type = ACTION_TEXTEDIT_ADD_CHAR;
        break;
    case RC_CMD_NAV_LEFT:
    case RC_CMD_CHAN_PREV:
        action.type = ACTION_TEXTEDIT_DEL_CHAR;
        break;
    case RC_CMD_NAV_UP:
        actionSet(ACTION_ENCODER, -1);
        break;
    case RC_CMD_NAV_DOWN:
        actionSet(ACTION_ENCODER, +1);
        break;
    }
}

static void actionNavigateCommon(RcCmd cmd)
{
    switch (cmd) {
    case RC_CMD_NAV_OK:
        actionSet(ACTION_OPEN_MENU, 0);
        break;
    case RC_CMD_NAV_BACK:
        actionSet(ACTION_MEDIA, MEDIAKEY_PLAY);
        break;
    case RC_CMD_NAV_RIGHT:
        actionSet(ACTION_MEDIA, MEDIAKEY_FFWD);
        break;
    case RC_CMD_NAV_LEFT:
        actionSet(ACTION_MEDIA, MEDIAKEY_REWIND);
        break;
    case RC_CMD_NAV_UP:
    case RC_CMD_CHAN_NEXT:
        actionSet(ACTION_MEDIA, MEDIAKEY_NEXT);
        break;
    case RC_CMD_NAV_DOWN:
    case RC_CMD_CHAN_PREV:
        actionSet(ACTION_MEDIA, MEDIAKEY_PREV);
        break;
    }
}

static void actionNextAudioGroup(void)
{
    AudioGroup group = audioGetGroup(priv.tune);

    do {
        group = (group + 1) % AUDIO_GROUP_END;
        priv.tune = audioGetFirstInGroup(group);
    } while (priv.tune == AUDIO_TUNE_INVALID);
}

static void actionNextAudioSubParam(void)
{
    AudioGroup group = audioGetGroup(priv.tune);

    if (group == AUDIO_GROUP_INVALID || priv.tune == AUDIO_TUNE_INVALID) {
        return;
    }

    do {
        priv.tune++;
        if (priv.tune >= AUDIO_TUNE_END) {
            priv.tune = AUDIO_TUNE_VOLUME;
        }
    } while (!audioIsTuneValid(priv.tune) || audioGetGroup(priv.tune) != group);
}

static int8_t actionGetNextAudioInput(int8_t diff)
{
    AudioProc *aProc = audioGet();

    int8_t input = aProc->par.input;
    int8_t inCnt = audioGetInputCount();

    int8_t ret = input;

    do {
        ret += diff;
        if (ret < 0) {
            ret = inCnt - 1;
        } else if (ret >= inCnt) {
            ret = 0;
        }
    } while ((amp->inType[ret] == IN_DISABLED) && (ret != input));

    return ret;
}

static void actionSetInput(int8_t value)
{
    ampSetInput(value);
}

static bool actionSetInputType(InputType value)
{
    AudioProc *aProc = audioGet();

    int8_t inCnt = audioGetInputCount();

    for (int8_t i = 0; i < inCnt; i++) {
        if (amp->inType[i] == value) {
            if (aProc->par.input != i) {
                actionSetInput(i);
                return true;
            }
            break;
        }
    }

    return false;
}

static void actionPostSetInput(void)
{
    priv.screenClear = true;
    priv.iconHint = ICON_EMPTY;
    screenSet(SCREEN_AUDIO_INPUT, 5000);
}

static bool isRemoteCmdRepeatable(RcCmd cmd)
{
    ScreenType scrMode = ampGet()->screen;
    AudioProc *aProc = audioGet();
    InputType inType = amp->inType[aProc->par.input];

    switch (cmd) {
    case RC_CMD_VOL_UP:
    case RC_CMD_VOL_DOWN:
        return true;
    case RC_CMD_NAV_UP:
    case RC_CMD_NAV_DOWN:
        switch (scrMode) {
        case SCREEN_AUDIO_PARAM:
            return true;
        }
        break;
    case RC_CMD_NAV_LEFT:
    case RC_CMD_NAV_RIGHT:
        switch (scrMode) {
        case SCREEN_AUDIO_INPUT:
            if (inType == IN_TUNER) {
                return true;
            }
        }
        break;
    }

    return false;
}

static void actionGetRemote(void)
{
    RcData rcData = rcRead(true);
    static RcCmd cmdPrev = RC_CMD_END;

    if (rcData.ready) {
        swTimSet(SW_TIM_RC_NOACION, 200);

        RcCmd cmd = rcGetCmd(&rcData);
        int32_t repTime = swTimGet(SW_TIM_RC_REPEAT);

        if (cmd != cmdPrev) {
            actionSet(ACTION_REMOTE, (int16_t)cmd);
            swTimSet(SW_TIM_RC_REPEAT, 1000);
            cmdPrev = cmd;
        } else {
            if (isRemoteCmdRepeatable(cmd)) {
                if (repTime < 500) {
                    actionSet(ACTION_REMOTE, (int16_t)cmd);
                }
            } else {
                if (repTime == 0) {
                    actionSet(ACTION_REMOTE, (int16_t)cmd);
                    swTimSet(SW_TIM_RC_REPEAT, 1000);
                }
            }
        }
    } else {
        if (swTimGet(SW_TIM_RC_NOACION) == 0) {
            swTimSet(SW_TIM_RC_NOACION, SW_TIM_OFF);
            swTimSet(SW_TIM_RC_REPEAT, 0);
            cmdPrev = RC_CMD_END;
        }
    }
}

static void stbyTimerChange(void)
{
    int32_t stbyTimer = swTimGet(SW_TIM_STBY);

    static const uint8_t stbyTimeMin[] = {
        2, 5, 10, 20, 40, 60, 90, 120, 180, 240,
    };

    for (uint8_t i = 0; i < sizeof (stbyTimeMin) / sizeof (stbyTimeMin[0]); i++) {
        int32_t stbyTime = 1000 * 60 * stbyTimeMin[i];
        if (stbyTimer < stbyTime) {
            swTimSet(SW_TIM_STBY, stbyTime + 999);
            break;
        }
        if (i == sizeof (stbyTimeMin) / sizeof (stbyTimeMin[0]) - 1) {
            swTimSet(SW_TIM_STBY, SW_TIM_OFF);
        }
    }
}

static void spModeChange(void)
{
    Spectrum *sp = spGet();

    sp->mode++;

    if (sp->mode > SP_MODE_WATERFALL) {
        sp->mode = SP_MODE_STEREO;
    } else if (sp->mode > SP_MODE_MIXED) {
        sp->mode = sp->flags & SP_FLAG_PEAKS ? SP_MODE_STEREO : SP_MODE_WATERFALL;
    }

    if (sp->mode == SP_MODE_STEREO) {
        sp->flags ^= SP_FLAG_PEAKS;
        settingsStore(PARAM_SPECTRUM_PEAKS, (sp->flags & SP_FLAG_PEAKS) == SP_FLAG_PEAKS);
    }

    priv.screenClear = true;
    settingsStore(PARAM_SPECTRUM_MODE, sp->mode);
}

static void tunerSendMediaKey(MediaKey key)
{
    swTimSet(SW_TIM_RDS_HOLD, SW_TIM_OFF);
    switch (key) {
    case MEDIAKEY_PREV:
        tunerMove(TUNER_DIR_DOWN);
        break;
    case MEDIAKEY_NEXT:
        tunerMove(TUNER_DIR_UP);
        break;
    case MEDIAKEY_REWIND:
        tunerSeek(TUNER_DIR_DOWN);
        break;
    case MEDIAKEY_FFWD:
        tunerSeek(TUNER_DIR_UP);
        break;
    default:
        break;
    }
}

static void usbSendMediaKey(MediaKey key)
{
#ifdef _ENABLE_USB
    switch (key) {
    case MEDIAKEY_PREV:
        usbHidSendMediaKey(HIDMEDIAKEY_PREV_TRACK);
        break;
    case MEDIAKEY_NEXT:
        usbHidSendMediaKey(HIDMEDIAKEY_NEXT_TRACK);
        break;
    case MEDIAKEY_STOP:
        usbHidSendMediaKey(HIDMEDIAKEY_STOP);
        break;
    case MEDIAKEY_PLAY:
        usbHidSendMediaKey(HIDMEDIAKEY_PLAY);
        break;
    case MEDIAKEY_PAUSE:
        usbHidSendMediaKey(HIDMEDIAKEY_PAUSE);
        break;
    case MEDIAKEY_REWIND:
        usbHidSendMediaKey(HIDMEDIAKEY_REWIND);
        break;
    case MEDIAKEY_FFWD:
        usbHidSendMediaKey(HIDMEDIAKEY_FFWD);
        break;
    case MEDIAKEY_MUTE:
        usbHidSendMediaKey(HIDMEDIAKEY_MUTE);
        break;
    default:
        break;
    }
#else
    (void)key;
#endif
}

static void ampSendMediaKey(MediaKey key)
{
    AudioProc *aProc = audioGet();
    InputType inType = amp->inType[aProc->par.input];

    switch (inType) {
    case IN_TUNER:
        tunerSendMediaKey(key);
        break;
    case IN_PC:
        usbSendMediaKey(key);
        break;
    case IN_MPD:
    case IN_KARADIO:
        mpcSendMediaKey(key);
        break;
    case IN_BLUETOOTH:
        btSendMediaKey(key);
        break;
    default:
        break;
    }
}

static void actionGetTimers(void)
{
    if (swTimGet(SW_TIM_AMP_INIT) == 0) {
        actionSet(ACTION_INIT_HW, 0);
    } else if (swTimGet(SW_TIM_RTC_INIT) == 0) {
        actionSet(ACTION_INIT_RTC, 0);
    } else if (swTimGet(SW_TIM_MPD_POWEROFF) == 0) {
        actionSet(ACTION_MPD_POWEROFF, 0);
    } else if (swTimGet(SW_TIM_SOFT_VOLUME) == 0) {
        actionSet(ACTION_RESTORE_VOLUME, priv.volume);
    } else if (swTimGet(SW_TIM_DIGIT_INPUT) == 0) {
        actionSet(ACTION_FINISH_DIGIT_INPUT, 0);
    } else if (swTimGet(SW_TIM_DISPLAY) == 0) {
        actionSet(ACTION_DISP_EXPIRED, 0);
    } else {
        int32_t swTimStby = swTimGet(SW_TIM_STBY);
        int32_t swTimSilence = swTimGet(SW_TIM_SILENCE);

        if (swTimStby == SW_TIM_OFF && swTimSilence == SW_TIM_OFF) {
            return;
        }

        if (swTimStby == 0 || swTimSilence == 0) {
            actionSet(ACTION_STANDBY, FLAG_ENTER);
            return;
        }

        switch (getScrDef()) {
        case SCREEN_SAVER:
        case SCREEN_SILENCE_TIMER:
        case SCREEN_STBY_TIMER:
            if (amp->screen != getScrDef()) {
                actionSet(ACTION_DISP_EXPIRED, -1);
            }
            break;
        }
    }
}

static void actionRemapBtnShort(void)
{
    switch (action.value) {
    case BTN_D0:
        actionSet(ACTION_STANDBY, FLAG_SWITCH);
        break;
    case BTN_D1:
        if (amp->screen == SCREEN_TIME) {
            actionSet(ACTION_RTC_MODE, 0);
        } else {
            actionSet(ACTION_AUDIO_INPUT_CHANGE, +1);
        }
        break;
    case BTN_D2:
        actionSet(ACTION_NAVIGATE, RC_CMD_NAV_BACK);
        break;
    case BTN_D3:
        actionSet(ACTION_NAVIGATE, RC_CMD_CHAN_PREV);
        break;
    case BTN_D4:
        actionSet(ACTION_NAVIGATE, RC_CMD_CHAN_NEXT);
        break;
    case BTN_D5:
        actionSet(ACTION_NAVIGATE, RC_CMD_NAV_OK);
        break;
    case ENC_A:
        actionSet(ACTION_ENCODER, -1);
        break;
    case ENC_B:
        actionSet(ACTION_ENCODER, +1);
        break;
    default:
        break;
    }
}
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

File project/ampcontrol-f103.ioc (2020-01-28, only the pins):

Mcu.UserName=STM32F103C8Tx
PA0-WKUP.GPIO_Label=LEFT
PA0-WKUP.Signal=ADCx_IN0
PA1.GPIO_Label=RIGHT
PA1.Signal=ADCx_IN1
PA10.GPIO_Label=RX
PA10.Signal=USART1_RX
PA11.Signal=USB_DM
PA12.Signal=USB_DP
PA13.GPIO_Label=MUTE/SWDIO
PA13.Signal=SYS_JTMS-SWDIO
PA14.GPIO_Label=STBY/SWCLK
PA14.Signal=SYS_JTCK-SWCLK
PA15.GPIO_Label=HW_RST
PA15.Signal=GPIO_Output
PA2.GPIO_Label=TX2
PA2.Signal=USART2_TX
PA3.GPIO_Label=RX2
PA3.Signal=USART2_RX
PA4.GPIO_Label=SD_NSS
PA4.Signal=SPI1_NSS
PA5.GPIO_Label=SD_SCK
PA5.Signal=SPI1_SCK
PA6.GPIO_Label=SD_MISO
PA6.Signal=SPI1_MISO
PA7.GPIO_Label=SD_MOSI
PA7.Signal=SPI1_MOSI
PA8.GPIO_Label=IR
PA8.Signal=GPXTI8
PA9.GPIO_Label=TX
PA9.Signal=USART1_TX
PB0.GPIO_Label=BTN_0
PB0.Signal=GPIO_Input
PB1.GPIO_Label=BTN_1
PB1.Signal=GPIO_Input
PB10.GPIO_Label=TX3
PB10.Signal=USART3_TX
PB11.GPIO_Label=RX3
PB11.Signal=USART3_RX
PB12.GPIO_Label=DISP_CS
PB12.Signal=SPI2_NSS
PB13.GPIO_Label=DISP_SCK
PB13.Signal=SPI2_SCK
PB14.GPIO_Label=DISP_DC
PB14.Signal=SPI2_MISO
PB15.GPIO_Label=DISP_SDI
PB15.Signal=SPI2_MOSI
PB2.GPIO_Label=BTN_2
PB2.Signal=GPIO_Input
PB3.GPIO_Label=BTN_3
PB3.Signal=GPIO_Input
PB4.GPIO_Label=BTN_4
PB4.Signal=GPIO_Input
PB5.GPIO_Label=BTN_5
PB5.Signal=GPIO_Input
PB6.GPIO_Label=ENC_A
PB6.Signal=GPIO_Input
PB7.GPIO_Label=ENC_B
PB7.Signal=GPIO_Input
PB8.GPIO_Label=SCL
PB8.Signal=I2C1_SCL
PB9.GPIO_Label=SDA
PB9.Signal=I2C1_SDA
PC13-TAMPER-RTC.GPIO_Label=DISP_BL
PC13-TAMPER-RTC.Signal=GPIO_Output
PC14-OSC32_IN.Signal=RCC_OSC32_IN
PC15-OSC32_OUT.Signal=RCC_OSC32_OUT
PD0-OSC_IN.Signal=RCC_OSC_IN
PD1-OSC_OUT.Signal=RCC_OSC_OUT

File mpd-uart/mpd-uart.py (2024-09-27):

import getopt
import signal
import sys
import threading
import time

import serial
import mpd

import socket
import subprocess


def do_meta(song):
    title = song.get('title', '')
    name = song.get('name', '')
    artist = song.get('artist', '')

    if title:
        if artist:
            name = artist + ' - ' + title
        else:
            name = title

    return name


class Console(object):
    def __init__(self, port, baudrate):
        self.serial = serial.Serial(port=port, baudrate=baudrate)
        self.alive = False
        self.reader_thread = None
        self.parse_cb = None
        self.write_lock = threading.Lock()

    def set_parse_cb(self, cb):
        self.parse_cb = cb

    def send(self, info):
        self.write_lock.acquire()
        print(">>>: " + info)
        self.serial.write(bytes(info + '\r\n', 'utf-8'))
        self.write_lock.release()

    def start(self):
        self.alive = True
        self.reader_thread = threading.Thread(target=self.reader_fn, name='reader')
        self.reader_thread.daemon = True
        self.reader_thread.start()

    def join(self):
        self.reader_thread.join()

    def reader_fn(self):
        while self.alive:
            try:
                str_seq = self.serial.read_until(serial.LF, 256)
                str_seq = str(str_seq, 'utf-8').strip()
                if self.parse_cb:
                    self.parse_cb(str_seq)
                if str_seq == 'quit':
                    self.alive = False
            except:
                pass


class NetworkChecker(object):
    def __init__(self):
        self.ip = "127.0.0.1"
        self.alive = False
        self.check_thread = None

    def start(self):
        self.alive = True
        self.check_thread = threading.Thread(target=self.check_fn, name='reader')
        self.check_thread.daemon = True
        self.check_thread.start()

    def join(self):
        self.check_thread.join()

    def get_ip(self):
        return self.ip

    def update_ip(self):
        s = socket.socket(socket.AF_INET, socket.SOCK_DGRAM)
        s.settimeout(1)

        try:
            s.connect(('8.8.8.8', 1))
            ip = s.getsockname()[0]
        except Exception:
            ip = '127.0.0.1'
        finally:
            s.close()
        return ip

    def check_fn(self):
        while self.alive:
            time.sleep(2)
            ip = self.update_ip()
            if ip != self.ip:
                self.ip = ip


class Player(object):
    def __init__(self, sport, baudrate, host, port):
        self.client = mpd.MPDClient()
        self.console = Console(port=sport, baudrate=baudrate)
        self.console.set_parse_cb(self.parse_handler)
        self.client.connect(host=host, port=port)
        self.alive = False
        self.notify_thread = None
        self.networkChecker = NetworkChecker()
        self.player_info = []
        self.cmd_queue = []

    def parse_cmd(self, cmd, status):
        elapsed = float(status.get('elapsed', 0))
        state = status.get('state', 'stop')

        cmd = str(cmd)

        if cmd == 'info':
            self.player_info = []
        if cmd == 'start':
            if state == 'stop':
                self.client.play()
            else:
                self.client.pause()
        if cmd == 'stop':
            self.client.stop()
        if cmd == 'pause':
            if state == 'stop':
                self.client.play()
            else:
                self.client.pause()
        if cmd == 'next':
            if state == 'play':
                self.client.next()
        if cmd == 'prev':
            if state == 'play':
                self.client.previous()
        if cmd == 'rewind':
            if state == 'play':
                pos = elapsed - 5
                if pos < 0:
                    pos = 0
            self.client.seekcur(pos)
        if cmd == 'ffwd':
            if state == 'play':
                pos = elapsed + 5
                self.client.seekcur(pos)
        if cmd.startswith('load'):
            playlists = self.client.listplaylists()
            pl_name = cmd[6:-2].strip()
            if next((pl for pl in playlists if pl['playlist'] == pl_name), False):
                self.client.clear()
                self.client.load(pl_name)
                self.client.play()
        if cmd == 'repeat':
            self.client.repeat(int(not int(status.get(cmd))))
        if cmd == 'random':
            self.client.random(int(not int(status.get(cmd))))
        if cmd == 'single':
            self.client.single(int(not int(status.get(cmd))))
        if cmd == 'consume':
            self.client.consume(int(not int(status.get(cmd))))
        if cmd == 'poweroff':
            try:
               subprocess.call(['sh', '/home/pi/poweroff.sh'])
            except:
                pass

    def notify_fn(self):
        while self.alive:
            self.update_player_info()
            if not self.cmd_queue:
                time.sleep(0.1)

    def signal_handler(self, sig, frame):
        self.console.send('##SYS.RESET')
        exit(0)

    def start(self):
        self.alive = True
        self.console.start()
        self.networkChecker.start()
        self.notify_thread = threading.Thread(target=self.notify_fn, name='notify')
        self.notify_thread.daemon = True
        self.notify_thread.start()
        signal.signal(signal.SIGTERM, self.signal_handler)
        signal.signal(signal.SIGINT, self.signal_handler)

    def join(self):
        self.console.join()
        self.networkChecker.join()
        self.notify_thread.join()

    def update_player_info(self):
        status = self.client.status()
        if self.cmd_queue:
            cmd = self.cmd_queue.pop(0)
            try:
                self.parse_cmd(cmd, status)
                status = self.client.status()
            except:
                pass
        song = self.client.currentsong()

        player_info = {
            'name': song.get('name', ''),
            'artist': song.get('artist', ''),
            'title': song.get('title', ''),
            'elapsed': float(status.get('elapsed', 0)),
            'duration': float(status.get('duration', 0)),
            'state': status.get('state'),
            'repeat': status.get('repeat'),
            'random': status.get('random'),
            'single': status.get('single'),
            'consume': status.get('consume'),
            'timestamp': time.time(),
            'ip': self.networkChecker.get_ip()
        }

        update_all = False
        if not self.player_info:
            self.player_info = player_info
            update_all = True

        update_name = player_info['name'] != self.player_info['name']
        update_title = player_info['title'] != self.player_info['title']
        update_artist = player_info['artist'] != self.player_info['artist']
        update_meta = update_name or update_title or update_artist
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

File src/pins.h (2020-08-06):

#ifndef PINS_H
#define PINS_H

#ifdef __cplusplus
extern "C" {
#endif

#include <stdbool.h>
#include <stdint.h>

#include "hwlibs.h"

// Mute and Standby lines
#define MUTE_Port               GPIOB
#define MUTE_Pin                LL_GPIO_PIN_11
#define STBY_Port               GPIOB
#define STBY_Pin                LL_GPIO_PIN_10

// Main I2C bus
#define AMP_I2C_Port            GPIOB
#define AMP_I2C_SCK_Pin         LL_GPIO_PIN_8
#define AMP_I2C_SDA_Pin         LL_GPIO_PIN_9

// SI470X Reset pins
#define SI470X_SCLK_Port        AMP_I2C_Port
#define SI470X_SCLK_Pin         AMP_I2C_SCK_Pin
#define SI470X_SDIO_Port        AMP_I2C_Port
#define SI470X_SDIO_Pin         AMP_I2C_SDA_Pin
// TODO: Use the same RST as display uses
#define SI470X_RST_Port         GPIOA
#define SI470X_RST_Pin          LL_GPIO_PIN_15

// USB pins
#define USB_DM_Port             GPIOA
#define USB_DM_Pin              LL_GPIO_PIN_11
#define USB_DP_Port             GPIOA
#define USB_DP_Pin              LL_GPIO_PIN_12

void pinsInit(void);

void pinsHwResetI2c(void);

#ifdef __cplusplus
}
#endif

#endif // PINS_H

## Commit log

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2018-06-23 Rework project structure and Makefile to be close to main ATmega32-based project
    [stm32f10x-openocd.cfg]
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2018-07-14 Rework actions and add decoder handling
    [actions.c, main.c]
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2018-08-12 Fix button read on S6D0139
    [pins.c]
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2018-09-01 Test flash write function
    [stm32f10x-openocd.cfg]
2018-09-02 Simplify ldscript and improve openocd config
    [stm32f10x-openocd.cfg]
2018-09-08 Fix output fonts with heigth not aligned by 8 bits
    [ili9341.c, lph9157.c, ls020.c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]
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2018-09-15 Fix wrong define for buttons
2018-09-16 Rework inputs and audio params
    [actions.c, eemul.h]
2018-09-24 Rework I2C driver
2018-10-10 Add document with pinout description
    [pins.ods]
2018-10-13 Fix SPI1 display conflict with I2C1
    There is a hardware bug when remapped SPI1 can't work with I2C1.
    To fix it LCD I2C now is I2C1, while main I2C is I2C2.
    Also, some pin rearrangements done for KS0108/ST7920
    [pins.h]
2018-10-13 Update pinout doc to fit latest changes
    [pins.ods]
2018-10-15 Partial rework I2C and add initial RDA5807 support
    [main.c, pins.c, pins.h]
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2018-10-20 Rework image drawing function
    [ili9341.c, lph9157.c]
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2018-10-28 Use undocumented STM32F103C8T6 flash area
    [stm32f10x-openocd.cfg]
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2018-11-07 Fix ILI9341-like displays in 16bit mode
    [ili9341.c, lph9157.c]
2018-11-18 Update pins description file
    [pins.ods]
2018-12-02 Add initial KiCad project
    [ampcontrol-f103.kicad_pcb, ampcontrol-f103.sch]
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2018-12-08 Swap display CS and RST to avoid RST conflict with I2C
    [ampcontrol-f103.sch, pins.ods]
2018-12-08 Fix fake START on reset
    [pins.c]
2018-12-09 Updated schematics
    [ampcontrol-f103.sch, pins.ods]
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2018-12-10 Useful make targets for backup/restore
    [stm32f10x-openocd.cfg]
2018-12-11 TDA731X: fix switch selection
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2018-12-12 Init optimization, refactoring and static analysis warnings fixes
    [actions.c, main.c]
2018-12-15 Add TDA7313 schematic
    [ampcontrol-f103.kicad_pcb, ampcontrol-f103.sch, tda7313.kicad_pcb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]
2018-12-15 PCB for TDA7313
    [tda7313.kicad_pcb]
2018-12-17 Update schematics
    [ampcontrol-f103.kicad_pcb, ampcontrol-f103.sch]
2018-12-18 Update and fix schematic
    [ampcontrol-f103.sch]
2018-12-21 Split display reset and Si470x one
    [pins.ods]
2018-12-29 Fix typo causing build error for SPI displays
2018-12-31 Fix some bugs with eeprom
    [eemul.h]
2018-12-31 Fix issues with audio params tuning
    [actions.c]
2019-01-08 Consider alternative pinout, with at least two UARTs availiable
    [pins.ods]
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2019-01-12 Move to alternative layout. Step 2: Swap I2C, use I2C1 remap
    [pins.c, pins.h]
2019-01-13 Move to alternative layout. Step 2: Swap DISP_DATA and ADC
    [pins.h]
2019-01-13 Arrange components on PCB
    [ampcontrol-f103_ili9341_8bit.kicad_pcb, ampcontrol-f103_ili9341_8bit.sch]
2019-01-13 Fix frame drawing in menu
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2019-01-19 Fix display emulator build
    [actions.c, ili9341.c, lph9157.c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]
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2019-01-21 Rework EE_EPROM parameters reading/storing
    [actions.c]
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2019-01-23 Fix hang on changing audio param if no audioproc is selected
    [actions.c]
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2019-01-26 Rework eeprom emulation - split API from code
    [actions.c, eemul.h, ili9341.c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]
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2019-02-01 Load stored in EEPROM stations
    [stm32f10x-openocd.cfg]
2019-02-02 Actions rework, navigation added
    [actions.c, main.c]
2019-02-04 Stations save/remove in Flash memory
    [stm32f10x-openocd.cfg]
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2019-02-06 Change boot configuration no schematic
    [ampcontrol-f103_ili9341_8bit.dsn, ampcontrol-f103_ili9341_8bit.kicad_pcb, ampcontrol-f103_ili9341_8bit.sch]
2019-02-11 Fix some bugs in menus
    [actions.c]
2019-02-23 Initial display-independent Kicad project
    [ampcontrol-f103.kicad_pcb, ampcontrol-f103.sch]
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2019-02-27 Universal PCB for ILI9341 PCB
    [ampcontrol-f103.dsn, ampcontrol-f103.kicad_pcb]
2019-02-27 Finish with ILI9341 SPI PCB
    [ampcontrol-f103.kicad_pcb, ampcontrol-f103.sch]
2019-02-27 Add sockets for arduino-pinout displays
    [ampcontrol-f103.kicad_pcb, ampcontrol-f103.sch]
2019-03-01 Buttons 0..6 correct emulation
2019-03-05 Move KiCad files to the top directory
    [ampcontrol-f103.dsn, ampcontrol-f103.kicad_pcb, ampcontrol-f103.sch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]
2019-03-17 Fix CH_UP/CH_DOWN from front panel
    [actions.c]
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2019-03-23 Fix build with SPI displays
2019-03-23 Fix clock setup from front panel
    [actions.c]
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2019-04-09 Kicad PCB: Fix missing connection for sdcard socket
    [ampcontrol-f103.kicad_pcb]
2019-04-09 Kicad: Fix arduino-specific pinout
    [ampcontrol-f103.kicad_pcb, ampcontrol-f103.sch]
2019-04-10 Unlock probably locked device on erase
    [stm32f10x-openocd.cfg]
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2019-05-07 Smal fix for CR1220 package
    [ampcontrol-f103.kicad_pcb]
2019-05-09 Fix Si470x initialization on power on
    [actions.c]
2019-05-09 Code refactoring and emuldisp build fix
    [actions.c]
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2019-05-23 Add block scheme for the whole device
    [block-sch.sch]
2019-05-26 Improve RTC init and fix silence timer
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2019-06-04 Fix volume control after audio flag
    [actions.c]
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2019-06-09 Correctly show mute flag
    [actions.c]
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2019-06-25 Add Kicad project for amplifier power supply
    [pwr_33x2.kicad_pcb, pwr_33x2.sch]
2019-07-04 Fix PCB bugs
    [ampcontrol-f103.kicad_pcb]
2019-07-18 Fix swapping pages and eeprom overflow
    [stm32f10x-openocd.cfg]
2019-07-20 Add Kicad karadio project
    [karadio-red.kicad_pcb, karadio-red.sch]
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2019-07-22 Add optional RAM to karadio project
    [karadio-red.kicad_pcb, karadio-red.sch]
2019-07-24 Make karadio project able to work with both 23LCV1024 and 23LC1024
    [karadio-red.kicad_pcb, karadio-red.sch]
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2019-08-03 Fix possible hang in UART receive handler
2019-08-10 Replace SEEK action with MEDIAKEY REWIND
    [actions.c]
2019-08-10 Replace CHAN action by MEDIA TRACK
    [actions.c]
2019-08-17 Rework and enable USART debug
    [main.c]
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2019-08-21 Rework and report audio params
    [actions.c]
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2019-08-24 Sync code with wl_103 project. Added STM32F303 files
    [stm32f103xb_openocd.cfg, stm32f303xc_openocd.cfg]
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2019-09-09 Fixes for F303 I2C
2019-09-09 Fixes for ADC
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2019-10-12 Fix Si4703 init after powerdown
2019-10-20 Fix possible I2C hung on F103
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2019-11-10 Remove old layouts from pins.ods
    [pins.ods]
2019-11-12 Fix I2C compile error on F303
2019-11-12 Fix brightness control in display emulator
    [pins.c, pins.h]
2019-11-14 Rework buttons handling
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2019-12-12 Base schematics for TDA7719
    [tda7719.kicad_pcb, tda7719.sch]
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2019-12-27 Schematic: map MUTE/STBY to PB11/PB10, that are de-facto have been used
    [ampcontrol-f103.kicad_pcb, ampcontrol-f103.sch]
2019-12-27 Fix MUTE/STBY on PB11/PB10
    [pins.c, pins.h]
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2020-01-11 Fix eemul for F303CB
    [eemul.h]
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2020-02-01 Reset USB on system loading
    [main.c, pins.c, pins.h]
2020-02-03 Fix mute for amp pin
2020-02-04 Small changes in schematic/PCB
    [ampcontrol-f103.kicad_pcb, ampcontrol-f103.sch]
2020-02-06 Move the sources to the subidir
    [stm32f103xb_openocd.cfg, stm32f303xc_openocd.cfg]
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2020-02-11 Fix I2C1 clock source
    [main.c]
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2020-02-25 Update config to use recent openocd on f103
    [stm32f103xb_openocd.cfg]
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2020-02-25 Fix flash definitions for STM32F3
    [eemul.h]
2020-03-02 Fix audio menu after power lost
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2020-06-02 Fix input on SPI displays
2020-06-14 Add FAN control circuit
    [fancontrol.sch]
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2020-11-03 Fix mounting holes on PCB for 2.8 display
    [ampcontrol-f103.kicad_pcb]
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2020-11-23 Fix STBY pin behaviour after entering STBY mode
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2021-01-23 Add GND to external SPI sockets
    [ampcontrol-f103.kicad_pcb, ampcontrol-f103.sch]
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2021-02-10 Rework software timers
2021-02-15 Fix hiding silence timer
2021-02-15 Rework standby timers and screensaver
    [amp_main.c]
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2021-02-18 Remove adc workaround due to fix in HAL library
2021-02-18 Fix spectrum mode changes
    [amp_main.c]
2021-02-26 Add LCD display connection schematics
    [lcd-connection.sch]
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2021-02-28 Add RPI power schematic
    [rpi_power.sch]
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2021-03-01 Filter short audio peaks in silence timer
    [amp_main.c]
2021-03-01 Fix rpi-power schematics
    [rpi_power.sch]
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2021-03-03 Fix fantom encoder events
    [amp_main.c]
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2021-03-15 Reset menu item by long press BTN_5
    [amp_main.c]
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2021-03-20 Fix pausing on MPD
    [mpd-uart.py]
2021-03-25 Use common audioflag set/reset function
    [amp_main.c]
2021-03-30 Remove menu reset functionality
    [amp_main.c]
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2021-06-15 BT: avoid screen clear on track change
    [amp_main.c]
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2022-02-19 Move ampcontrol-f103 to Kicad 6
    [ampcontrol-f103.dsn, ampcontrol-f103.kicad_pcb, ampcontrol-f103.kicad_sch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]
2022-02-19 Move block-sch to Kicad 6
    [block-sch.kicad_sch, block-sch.sch]
2022-02-19 Move fancontrol to Kicad 6
    [fancontrol.kicad_sch, fancontrol.sch]
2022-02-19 Move karadio-red to Kicad 6
    [karadio-red.kicad_pcb, karadio-red.kicad_sch, karadio-red.sch]
2022-02-19 Move lcd-connection to Kicad 6
    [lcd-connection.kicad_sch, lcd-connection.sch]
2022-02-19 Move pwr_33x2 to Kicad 6
    [pwr_33x2.kicad_pcb, pwr_33x2.kicad_sch, pwr_33x2.sch]
2022-02-19 Move rpi_power to Kicad 6
    [rpi_power.kicad_sch, rpi_power.sch]
2022-02-19 Move tda7313 to Kicad 6
    [tda7313.kicad_pcb, tda7313.kicad_sch, tda7313.sch]
2022-02-19 Move tda7719 to Kicad 6
    [tda7719.kicad_pcb, tda7719.kicad_sch, tda7719.sch]
2022-04-14 Swap MUTE and STBY in pin description
    [pins.ods]
2022-04-14 Swap MUTE and STBY in schematic, with no PCB change
    [ampcontrol-f103.kicad_pcb, ampcontrol-f103.kicad_sch]
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2024-03-09 Fix typos in filters for TDA7418/TDA7719
2024-03-09 Fix some typos in filters for TDA7719
    They are not used in code, but let them be correct
2024-04-30 kicad: sch: Mark R25 as not installed
    [ampcontrol-f103.kicad_sch]
2024-06-01 Update ampcontrol-f103 to Kicad 7
    [ampcontrol-f103.kicad_pcb]
2024-06-01 Update block-sch to Kicad 7
    [block-sch.kicad_sch]
2024-06-01 Update fancontrol to Kicad 7
    [fancontrol.kicad_sch]
2024-06-01 Update karadio-red to Kicad 7
    [karadio-red.kicad_pcb, karadio-red.kicad_sch]
2024-06-01 Update lcd-connection to Kicad 7
    [lcd-connection.kicad_sch]
2024-06-01 Update p2r_33x2 to Kicad 7
    [pwr_33x2.kicad_pcb, pwr_33x2.kicad_sch]
2024-06-01 Update rpi_power to Kicad 7
    [rpi_power.kicad_sch]
2024-06-01 Update tda7313 to Kicad 7
    [tda7313.kicad_sch]
2024-06-01 Update tda7919 to Kicad 7
    [tda7719.kicad_pcb, tda7719.kicad_sch]
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
